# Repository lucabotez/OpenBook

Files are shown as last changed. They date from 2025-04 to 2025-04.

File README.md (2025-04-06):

Botez Luca, 334CA

# OpenBook

## About
This project is a minimalist eBook Reader called OpenBook, built on the ESP32-C6 platform and equipped with a 7.5-inch e-paper display, a Li-Po battery, USB-C charging, and physical control buttons.

The device is designed to be energy-efficient and easy to use, featuring a simple interface controlled via GPIOs, with text display functions aimed at providing an optimal e-reading experience.

## Block Diagram

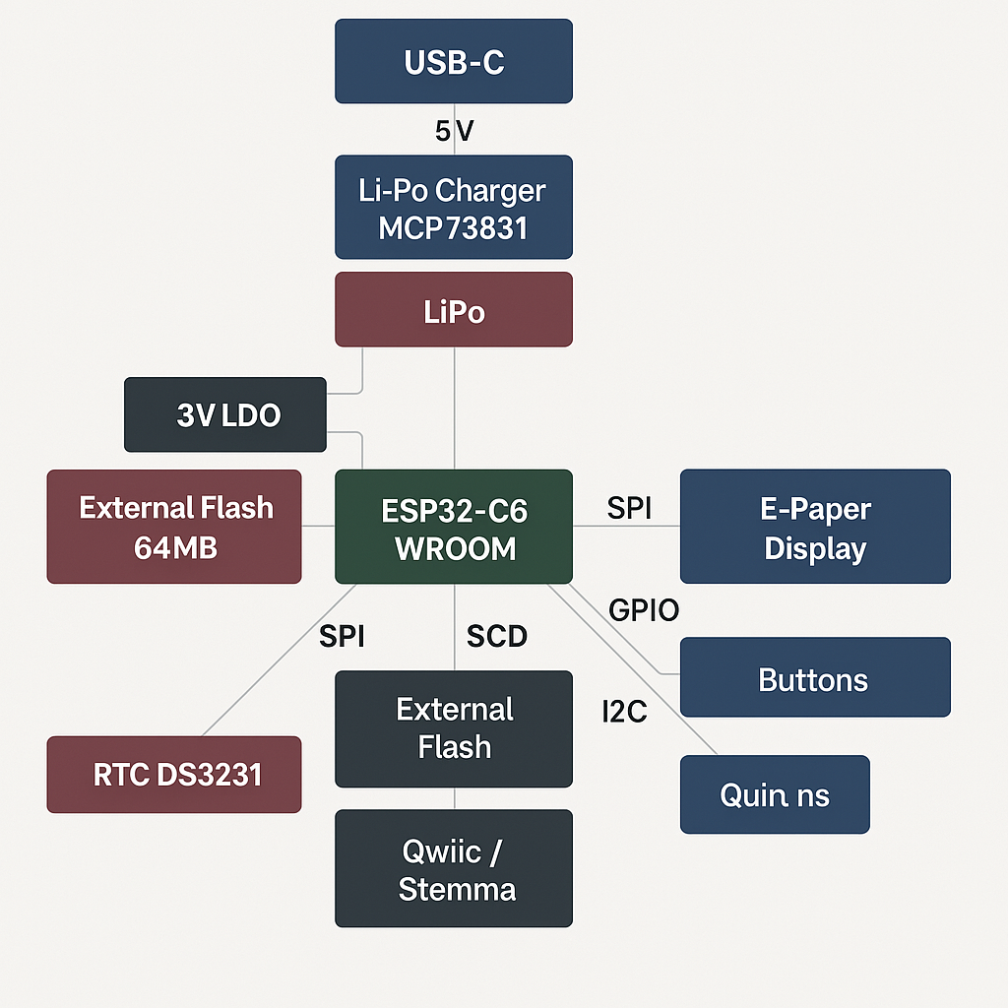
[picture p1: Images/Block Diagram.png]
Block Diagram


## BOM (Bill of Materials)

| Component | Purchase Link | Datasheet |
|---|---|---|
| BOOT_BUTTON | [https://ro.mouser.com/ProductDetail/Panasonic/EVQ-P7L01P](https://ro.mouser.com/ProductDetail/Panasonic/EVQ-P7L01P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) | https://componentsearchengine.com/Datasheets/2/EVQP7L01P.pdf |
| C1 | [https://ro.mouser.com/ProductDetail/YAGEO/CC0402MRX5R5BB106](https://ro.mouser.com/ProductDetail/YAGEO/CC0402MRX5R5BB106?qs=zEY9bCHj09eCmUJdZuS5Lg%3D%3D) | https://componentsearchengine.com/Datasheets/2/CC0402MRX5R5BB106.pdf |
| C1_BAT | [https://ro.mouser.com/ProductDetail/YAGEO/CC0402MRX5R5BB106](https://ro.mouser.com/ProductDetail/YAGEO/CC0402MRX5R5BB106?qs=zEY9bCHj09eCmUJdZuS5Lg%3D%3D) | https://componentsearchengine.com/Datasheets/2/CC0402MRX5R5BB106.pdf |
| C1_BAT2 | [https://ro.mouser.com/ProductDetail/YAGEO/CC0402MRX5R5BB106](https://ro.mouser.com/ProductDetail/YAGEO/CC0402MRX5R5BB106?qs=zEY9bCHj09eCmUJdZuS5Lg%3D%3D) | https://componentsearchengine.com/Datasheets/2/CC0402MRX5R5BB106.pdf |
| C2 | [https://ro.mouser.com/ProductDetail/YAGEO/CC0402MRX5R5BB106](https://ro.mouser.com/ProductDetail/YAGEO/CC0402MRX5R5BB106?qs=zEY9bCHj09eCmUJdZuS5Lg%3D%3D) | https://componentsearchengine.com/Datasheets/2/CC0402MRX5R5BB106.pdf |
| C2_BAT | [https://ro.mouser.com/ProductDetail/YAGEO/CC0402MRX5R5BB106](https://ro.mouser.com/ProductDetail/YAGEO/CC0402MRX5R5BB106?qs=zEY9bCHj09eCmUJdZuS5Lg%3D%3D) | https://componentsearchengine.com/Datasheets/2/CC0402MRX5R5BB106.pdf |
| C3 | [https://ro.mouser.com/ProductDetail/YAGEO/CC0402MRX5R5BB106](https://ro.mouser.com/ProductDetail/YAGEO/CC0402MRX5R5BB106?qs=zEY9bCHj09eCmUJdZuS5Lg%3D%3D) | https://componentsearchengine.com/Datasheets/2/CC0402MRX5R5BB106.pdf |
| C4 | [https://ro.mouser.com/ProductDetail/YAGEO/CC0402MRX5R5BB106](https://ro.mouser.com/ProductDetail/YAGEO/CC0402MRX5R5BB106?qs=zEY9bCHj09eCmUJdZuS5Lg%3D%3D) | https://componentsearchengine.com/Datasheets/2/CC0402MRX5R5BB106.pdf |
| C4_USB | [https://ro.mouser.com/ProductDetail/YAGEO/CC0402MRX5R5BB106](https://ro.mouser.com/ProductDetail/YAGEO/CC0402MRX5R5BB106?qs=zEY9bCHj09eCmUJdZuS5Lg%3D%3D) | https://componentsearchengine.com/Datasheets/2/CC0402MRX5R5BB106.pdf |
| C5 | [https://ro.mouser.com/ProductDetail/YAGEO/CC0402MRX5R5BB106](https://ro.mouser.com/ProductDetail/YAGEO/CC0402MRX5R5BB106?qs=zEY9bCHj09eCmUJdZuS5Lg%3D%3D) | https://componentsearchengine.com/Datasheets/2/CC0402MRX5R5BB106.pdf |
| C5_USB | [https://ro.mouser.com/ProductDetail/YAGEO/CC0402MRX5R5BB106](https://ro.mouser.com/ProductDetail/YAGEO/CC0402MRX5R5BB106?qs=zEY9bCHj09eCmUJdZuS5Lg%3D%3D) | https://componentsearchengine.com/Datasheets/2/CC0402MRX5R5BB106.pdf |
| C6 | [https://ro.mouser.com/ProductDetail/YAGEO/CC0402MRX5R5BB106](https://ro.mouser.com/ProductDetail/YAGEO/CC0402MRX5R5BB106?qs=zEY9bCHj09eCmUJdZuS5Lg%3D%3D) | https://componentsearchengine.com/Datasheets/2/CC0402MRX5R5BB106.pdf |
| C7 | [https://ro.mouser.com/ProductDetail/YAGEO/CC0402MRX5R5BB106](https://ro.mouser.com/ProductDetail/YAGEO/CC0402MRX5R5BB106?qs=zEY9bCHj09eCmUJdZuS5Lg%3D%3D) | https://componentsearchengine.com/Datasheets/2/CC0402MRX5R5BB106.pdf |
| C8 | [https://ro.mouser.com/ProductDetail/YAGEO/CC0402MRX5R5BB106](https://ro.mouser.com/ProductDetail/YAGEO/CC0402MRX5R5BB106?qs=zEY9bCHj09eCmUJdZuS5Lg%3D%3D) | https://componentsearchengine.com/Datasheets/2/CC0402MRX5R5BB106.pdf |
| C9 | [https://ro.mouser.com/ProductDetail/YAGEO/CC0402MRX5R5BB106](https://ro.mouser.com/ProductDetail/YAGEO/CC0402MRX5R5BB106?qs=zEY9bCHj09eCmUJdZuS5Lg%3D%3D) | https://componentsearchengine.com/Datasheets/2/CC0402MRX5R5BB106.pdf |
| C10 | [https://ro.mouser.com/ProductDetail/YAGEO/CC0402MRX5R5BB106](https://ro.mouser.com/ProductDetail/YAGEO/CC0402MRX5R5BB106?qs=zEY9bCHj09eCmUJdZuS5Lg%3D%3D) | https://componentsearchengine.com/Datasheets/2/CC0402MRX5R5BB106.pdf |
| C10_SUPERCAP | [https://ro.mouser.com/ProductDetail/Seiko-Semiconductors/CPH3225A](https://ro.mouser.com/ProductDetail/Seiko-Semiconductors/CPH3225A?qs=3etwrb1wR%252BhUOph6lAO7eg%3D%3D) | https://ro.mouser.com/datasheet/2/360/Seiko_Instruments_MicroBattery_E_20230330_2024Jan_-3561061.pdf |
| CHANGE_BUTTON | [https://ro.mouser.com/ProductDetail/Panasonic/EVQ-P7L01P](https://ro.mouser.com/ProductDetail/Panasonic/EVQ-P7L01P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) | https://componentsearchengine.com/Datasheets/2/EVQP7L01P.pdf |
| C_DELAY | [https://ro.mouser.com/ProductDetail/YAGEO/CC0402MRX5R5BB106](https://ro.mouser.com/ProductDetail/YAGEO/CC0402MRX5R5BB106?qs=zEY9bCHj09eCmUJdZuS5Lg%3D%3D) | https://componentsearchengine.com/Datasheets/2/CC0402MRX5R5BB106.pdf |
| D1 | [https://ro.mouser.com/ProductDetail/STMicroelectronics/USBLC6-2SC6Y](https://ro.mouser.com/ProductDetail/STMicroelectronics/USBLC6-2SC6Y?qs=gNDSiZmRJS%2FOgDexvXkdow%3D%3D) | https://ro.mouser.com/datasheet/2/389/usblc6_2sc6y-1852505.pdf |
| D2 | [https://ro.mouser.com/ProductDetail/KYOCERA-AVX/SD0805S020S1R0](https://ro.mouser.com/ProductDetail/KYOCERA-AVX/SD0805S020S1R0?qs=jCA%252BPfw4LHbpkAoSnwrdjw%3D%3D) | https://ro.mouser.com/datasheet/2/40/schottky-3165252.pdf |
| D3 | [https://ro.mouser.com/ProductDetail/Vishay-Semiconductors/MBR0530](https://ro.mouser.com/ProductDetail/Vishay-Semiconductors/MBR0530?qs=HoksaeI1MJOP4GvpzMgEDg%3D%3D) | https://www.onsemi.com/pdf/datasheet/mbr0530-d.pdf |
| D4 | [https://ro.mouser.com/ProductDetail/Vishay-Semiconductors/MBR0530](https://ro.mouser.com/ProductDetail/Vishay-Semiconductors/MBR0530?qs=HoksaeI1MJOP4GvpzMgEDg%3D%3D) | https://www.onsemi.com/pdf/datasheet/mbr0530-d.pdf |
| D5 | [https://ro.mouser.com/ProductDetail/Vishay-Semiconductors/MBR0530](https://ro.mouser.com/ProductDetail/Vishay-Semiconductors/MBR0530?qs=HoksaeI1MJOP4GvpzMgEDg%3D%3D) | https://www.onsemi.com/pdf/datasheet/mbr0530-d.pdf |
| D6 | [https://ro.mouser.com/ProductDetail/Littelfuse/PGB1010603MR](https://ro.mouser.com/ProductDetail/Littelfuse/PGB1010603MR?qs=gu7KAQ731URLg4GSnNNN7Q%3D%3D) | https://www.littelfuse.com/assetdocs/pulseguard-esd-suppressors-pgb1-datasheet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 |
| D7 | [https://ro.mouser.com/ProductDetail/KYOCERA-AVX/SD0805S020S1R0](https://ro.mouser.com/ProductDetail/KYOCERA-AVX/SD0805S020S1R0?qs=jCA%252BPfw4LHbpkAoSnwrdjw%3D%3D) | https://ro.mouser.com/datasheet/2/40/schottky-3165252.pdf |
| D8 | [https://ro.mouser.com/ProductDetail/Littelfuse/PGB1010603MR](https://ro.mouser.com/ProductDetail/Littelfuse/PGB1010603MR?qs=gu7KAQ731URLg4GSnNNN7Q%3D%3D) | https://www.littelfuse.com/assetdocs/pulseguard-esd-suppressors-pgb1-datasheet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 |
| D9 | [https://ro.mouser.com/ProductDetail/Littelfuse/PGB1010603MR](https://ro.mouser.com/ProductDetail/Littelfuse/PGB1010603MR?qs=gu7KAQ731URLg4GSnNNN7Q%3D%3D) | https://www.littelfuse.com/assetdocs/pulseguard-esd-suppressors-pgb1-datasheet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 |
| D10 | [https://ro.mouser.com/ProductDetail/Littelfuse/PGB1010603MR](https://ro.mouser.com/ProductDetail/Littelfuse/PGB1010603MR?qs=gu7KAQ731URLg4GSnNNN7Q%3D%3D) | https://www.littelfuse.com/assetdocs/pulseguard-esd-suppressors-pgb1-datasheet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 |
| D11 | [https://ro.mouser.com/ProductDetail/Littelfuse/PGB1010603MR](https://ro.mouser.com/ProductDetail/Littelfuse/PGB1010603MR?qs=gu7KAQ731URLg4GSnNNN7Q%3D%3D) | https://www.littelfuse.com/assetdocs/pulseguard-esd-suppressors-pgb1-datasheet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 |
| D12 | [https://ro.mouser.com/ProductDetail/Littelfuse/PGB1010603MR](https://ro.mouser.com/ProductDetail/Littelfuse/PGB1010603MR?qs=gu7KAQ731URLg4GSnNNN7Q%3D%3D) | https://www.littelfuse.com/assetdocs/pulseguard-esd-suppressors-pgb1-datasheet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 |
| EPD_C1 | [https://ro.mouser.com/ProductDetail/YAGEO/CC0402MRX5R5BB106](https://ro.mouser.com/ProductDetail/YAGEO/CC0402MRX5R5BB106?qs=zEY9bCHj09eCmUJdZuS5Lg%3D%3D) | https://componentsearchengine.com/Datasheets/2/CC0402MRX5R5BB106.pdf |
| EPD_C2 | [https://ro.mouser.com/ProductDetail/YAGEO/CC0402MRX5R5BB106](https://ro.mouser.com/ProductDetail/YAGEO/CC0402MRX5R5BB106?qs=zEY9bCHj09eCmUJdZuS5Lg%3D%3D) | https://componentsearchengine.com/Datasheets/2/CC0402MRX5R5BB106.pdf |
| EPD_C3 | [https://ro.mouser.com/ProductDetail/YAGEO/CC0402MRX5R5BB106](https://ro.mouser.com/ProductDetail/YAGEO/CC0402MRX5R5BB106?qs=zEY9bCHj09eCmUJdZuS5Lg%3D%3D) | https://componentsearchengine.com/Datasheets/2/CC0402MRX5R5BB106.pdf |
| EPD_C4 | [https://ro.mouser.com/ProductDetail/YAGEO/CC0402MRX5R5BB106](https://ro.mouser.com/ProductDetail/YAGEO/CC0402MRX5R5BB106?qs=zEY9bCHj09eCmUJdZuS5Lg%3D%3D) | https://componentsearchengine.com/Datasheets/2/CC0402MRX5R5BB106.pdf |
| EPD_C5 | [https://ro.mouser.com/ProductDetail/YAGEO/CC0402MRX5R5BB106](https://ro.mouser.com/ProductDetail/YAGEO/CC0402MRX5R5BB106?qs=zEY9bCHj09eCmUJdZuS5Lg%3D%3D) | https://componentsearchengine.com/Datasheets/2/CC0402MRX5R5BB106.pdf |
| EPD_C6 | [https://ro.mouser.com/ProductDetail/YAGEO/CC0402MRX5R5BB106](https://ro.mouser.com/ProductDetail/YAGEO/CC0402MRX5R5BB106?qs=zEY9bCHj09eCmUJdZuS5Lg%3D%3D) | https://componentsearchengine.com/Datasheets/2/CC0402MRX5R5BB106.pdf |
| EPD_C7 | [https://ro.mouser.com/ProductDetail/YAGEO/CC0402MRX5R5BB106](https://ro.mouser.com/ProductDetail/YAGEO/CC0402MRX5R5BB106?qs=zEY9bCHj09eCmUJdZuS5Lg%3D%3D) | https://componentsearchengine.com/Datasheets/2/CC0402MRX5R5BB106.pdf |
| EPD_C8 | [https://ro.mouser.com/ProductDetail/YAGEO/CC0402MRX5R5BB106](https://ro.mouser.com/ProductDetail/YAGEO/CC0402MRX5R5BB106?qs=zEY9bCHj09eCmUJdZuS5Lg%3D%3D) | https://componentsearchengine.com/Datasheets/2/CC0402MRX5R5BB106.pdf |
| EPD_C9 | [https://ro.mouser.com/ProductDetail/YAGEO/CC0402MRX5R5BB106](https://ro.mouser.com/ProductDetail/YAGEO/CC0402MRX5R5BB106?qs=zEY9bCHj09eCmUJdZuS5Lg%3D%3D) | https://componentsearchengine.com/Datasheets/2/CC0402MRX5R5BB106.pdf |
| EPD_C10 | [https://ro.mouser.com/ProductDetail/YAGEO/CC0402MRX5R5BB106](https://ro.mouser.com/ProductDetail/YAGEO/CC0402MRX5R5BB106?qs=zEY9bCHj09eCmUJdZuS5Lg%3D%3D) | https://componentsearchengine.com/Datasheets/2/CC0402MRX5R5BB106.pdf |
| EPD_C11 | [https://ro.mouser.com/ProductDetail/YAGEO/CC0402MRX5R5BB106](https://ro.mouser.com/ProductDetail/YAGEO/CC0402MRX5R5BB106?qs=zEY9bCHj09eCmUJdZuS5Lg%3D%3D) | https://componentsearchengine.com/Datasheets/2/CC0402MRX5R5BB106.pdf |
| EPD_C12 | [https://ro.mouser.com/ProductDetail/YAGEO/CC0402MRX5R5BB106](https://ro.mouser.com/ProductDetail/YAGEO/CC0402MRX5R5BB106?qs=zEY9bCHj09eCmUJdZuS5Lg%3D%3D) | https://componentsearchengine.com/Datasheets/2/CC0402MRX5R5BB106.pdf |
| IC1 | [https://ro.mouser.com/ProductDetail/ROHM-Semiconductor/BD5229G-TR](https://ro.mouser.com/ProductDetail/ROHM-Semiconductor/BD5229G-TR?qs=4kLU8WoGk0vvnhrrYwdszw%3D%3D) | https://fscdn.rohm.com/en/products/databook/datasheet/ic/power/voltage_detector/bd52xxg-e.pdf |
| IC4 | [https://ro.mouser.com/ProductDetail/Torex-Semiconductor/XC6220A331MR-G](https://ro.mouser.com/ProductDetail/Torex-Semiconductor/XC6220A331MR-G?qs=AsjdqWjXhJ8ZSWznL1J0gg%3D%3D) | https://ro.mouser.com/datasheet/2/760/xc6220-3371556.pdf |
| J1 | [https://ro.mouser.com/ProductDetail/Hirose-Connector/FH34SRJ-24S-0.5SH99](https://ro.mouser.com/ProductDetail/Hirose-Connector/FH34SRJ-24S-0.5SH99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) | https://ro.mouser.com/datasheet/2/185/FH34SRJ_24S_0_5SH_99__CL0580_1255_6_99_2DDrawing_0-1615044.pdf |
| J2 | [https://ro.mouser.com/ProductDetail/GCT/USB4110-GF-A](https://ro.mouser.com/ProductDetail/GCT/USB4110-GF-A?qs=KUoIvG%2F9IlYiZvIXQjyJeA%3D%3D) | https://ro.mouser.com/datasheet/2/837/GCT_USB4110_Product_Drawing___20k_cycles-3455479.pdf |
| J3 | [https://ro.mouser.com/ProductDetail/SparkFun/PRT-14417](https://ro.mouser.com/ProductDetail/SparkFun/PRT-14417?qs=wd5RIQLrsJhgdz%2FpmZ%2F3GQ%3D%3D) | https://ro.mouser.com/datasheet/2/813/Qwiic_Connector_Datasheet-1223982.pdf |
| J4 | https://store.comet.srl.ro/Catalogue/Product/43497/ | https://store.comet.bg/download-file.php?id=8824 |
| L1 | [https://ro.mouser.com/ProductDetail/Wurth-Elektronik/744043680](https://ro.mouser.com/ProductDetail/Wurth-Elektronik/744043680?qs=PGXP4M47uW6VkZq%252BkzjrHA%3D%3D) | https://www.we-online.com/components/products/datasheet/744043680.pdf |
| PFMF.050.1 | [https://ro.mouser.com/ProductDetail/KEMET/VE1812K401R050](https://ro.mouser.com/ProductDetail/KEMET/VE1812K401R050?qs=OycAS1CGnlizCtaoDVbQTA%3D%3D) | https://ro.mouser.com/datasheet/2/447/KEM_V0003_VE-3316901.pdf |
| Q1 | [https://ro.mouser.com/ProductDetail/Diodes-Incorporated/DMG2305UX-7](https://ro.mouser.com/ProductDetail/Diodes-Incorporated/DMG2305UX-7?qs=L1DZKBg7t5F%2FNBHrjfxC%252Bg%3D%3D) | https://www.diodes.com/assets/Datasheets/DMG2305UX.pdf |
| Q2 | [https://ro.mouser.com/ProductDetail/Diodes-Incorporated/DMG2305UX-7](https://ro.mouser.com/ProductDetail/Diodes-Incorporated/DMG2305UX-7?qs=L1DZKBg7t5F%2FNBHrjfxC%252Bg%3D%3D) | https://www.diodes.com/assets/Datasheets/DMG2305UX.pdf |
| Q3 | [https://ro.mouser.com/ProductDetail/Vishay-Semiconductors/SI1308EDL-T1-GE3](https://ro.mouser.com/ProductDetail/Vishay-Semiconductors/SI1308EDL-T1-GE3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) | https://www.vishay.com/docs/63399/si1308edl.pdf |
| R1 | [https://ro.mouser.com/ProductDetail/YAGEO/RC0402FR-07100KL](https://ro.mouser.com/ProductDetail/YAGEO/RC0402FR-07100KL?qs=mnq%2FyloZIXzTlUn7JAHSWg%3D%3D) | https://ro.mouser.com/datasheet/2/447/YAGEO_PYu_RC_Group_51_RoHS_L_12-3313492.pdf |
| R1_PINH | [https://ro.mouser.com/ProductDetail/YAGEO/RC0402FR-07100KL](https://ro.mouser.com/ProductDetail/YAGEO/RC0402FR-07100KL?qs=mnq%2FyloZIXzTlUn7JAHSWg%3D%3D) | https://ro.mouser.com/datasheet/2/447/YAGEO_PYu_RC_Group_51_RoHS_L_12-3313492.pdf |
| R1_PINH1 | [https://ro.mouser.com/ProductDetail/YAGEO/RC0402FR-07100KL](https://ro.mouser.com/ProductDetail/YAGEO/RC0402FR-07100KL?qs=mnq%2FyloZIXzTlUn7JAHSWg%3D%3D) | https://ro.mouser.com/datasheet/2/447/YAGEO_PYu_RC_Group_51_RoHS_L_12-3313492.pdf |
| R1_BAT | [https://ro.mouser.com/ProductDetail/YAGEO/RC0402FR-07100KL](https://ro.mouser.com/ProductDetail/YAGEO/RC0402FR-07100KL?qs=mnq%2FyloZIXzTlUn7JAHSWg%3D%3D) | https://ro.mouser.com/datasheet/2/447/YAGEO_PYu_RC_Group_51_RoHS_L_12-3313492.pdf |
| R1_PWRUSB | [https://ro.mouser.com/ProductDetail/YAGEO/RC0402FR-07100KL](https://ro.mouser.com/ProductDetail/YAGEO/RC0402FR-07100KL?qs=mnq%2FyloZIXzTlUn7JAHSWg%3D%3D) | https://ro.mouser.com/datasheet/2/447/YAGEO_PYu_RC_Group_51_RoHS_L_12-3313492.pdf |
| R2 | [https://ro.mouser.com/ProductDetail/YAGEO/RC0402FR-07100KL](https://ro.mouser.com/ProductDetail/YAGEO/RC0402FR-07100KL?qs=mnq%2FyloZIXzTlUn7JAHSWg%3D%3D) | https://ro.mouser.com/datasheet/2/447/YAGEO_PYu_RC_Group_51_RoHS_L_12-3313492.pdf |
| R2_PINH | [https://ro.mouser.com/ProductDetail/YAGEO/RC0402FR-07100KL](https://ro.mouser.com/ProductDetail/YAGEO/RC0402FR-07100KL?qs=mnq%2FyloZIXzTlUn7JAHSWg%3D%3D) | https://ro.mouser.com/datasheet/2/447/YAGEO_PYu_RC_Group_51_RoHS_L_12-3313492.pdf |
| R2_PINH1 | [https://ro.mouser.com/ProductDetail/YAGEO/RC0402FR-07100KL](https://ro.mouser.com/ProductDetail/YAGEO/RC0402FR-07100KL?qs=mnq%2FyloZIXzTlUn7JAHSWg%3D%3D) | https://ro.mouser.com/datasheet/2/447/YAGEO_PYu_RC_Group_51_RoHS_L_12-3313492.pdf |
| R2_USB | [https://ro.mouser.com/ProductDetail/YAGEO/RC0402FR-07100KL](https://ro.mouser.com/ProductDetail/YAGEO/RC0402FR-07100KL?qs=mnq%2FyloZIXzTlUn7JAHSWg%3D%3D) | https://ro.mouser.com/datasheet/2/447/YAGEO_PYu_RC_Group_51_RoHS_L_12-3313492.pdf |
| R2_USB1 | [https://ro.mouser.com/ProductDetail/YAGEO/RC0402FR-07100KL](https://ro.mouser.com/ProductDetail/YAGEO/RC0402FR-07100KL?qs=mnq%2FyloZIXzTlUn7JAHSWg%3D%3D) | https://ro.mouser.com/datasheet/2/447/YAGEO_PYu_RC_Group_51_RoHS_L_12-3313492.pdf |
| R2_BAT | [https://ro.mouser.com/ProductDetail/YAGEO/RC0402FR-07100KL](https://ro.mouser.com/ProductDetail/YAGEO/RC0402FR-07100KL?qs=mnq%2FyloZIXzTlUn7JAHSWg%3D%3D) | https://ro.mouser.com/datasheet/2/447/YAGEO_PYu_RC_Group_51_RoHS_L_12-3313492.pdf |
| R3 | [https://ro.mouser.com/ProductDetail/YAGEO/RC0402FR-07100KL](https://ro.mouser.com/ProductDetail/YAGEO/RC0402FR-07100KL?qs=mnq%2FyloZIXzTlUn7JAHSWg%3D%3D) | https://ro.mouser.com/datasheet/2/447/YAGEO_PYu_RC_Group_51_RoHS_L_12-3313492.pdf |
| R4 | [https://ro.mouser.com/ProductDetail/YAGEO/RC0402FR-07100KL](https://ro.mouser.com/ProductDetail/YAGEO/RC0402FR-07100KL?qs=mnq%2FyloZIXzTlUn7JAHSWg%3D%3D) | https://ro.mouser.com/datasheet/2/447/YAGEO_PYu_RC_Group_51_RoHS_L_12-3313492.pdf |
| R5 | [https://ro.mouser.com/ProductDetail/YAGEO/RC0402FR-07100KL](https://ro.mouser.com/ProductDetail/YAGEO/RC0402FR-07100KL?qs=mnq%2FyloZIXzTlUn7JAHSWg%3D%3D) | https://ro.mouser.com/datasheet/2/447/YAGEO_PYu_RC_Group_51_RoHS_L_12-3313492.pdf |
| R6 | [https://ro.mouser.com/ProductDetail/YAGEO/RC0402FR-07100KL](https://ro.mouser.com/ProductDetail/YAGEO/RC0402FR-07100KL?qs=mnq%2FyloZIXzTlUn7JAHSWg%3D%3D) | https://ro.mouser.com/datasheet/2/447/YAGEO_PYu_RC_Group_51_RoHS_L_12-3313492.pdf |
| R7 | [https://ro.mouser.com/ProductDetail/YAGEO/RC0402FR-07100KL](https://ro.mouser.com/ProductDetail/YAGEO/RC0402FR-07100KL?qs=mnq%2FyloZIXzTlUn7JAHSWg%3D%3D) | https://ro.mouser.com/datasheet/2/447/YAGEO_PYu_RC_Group_51_RoHS_L_12-3313492.pdf |
| R8 | [https://ro.mouser.com/ProductDetail/YAGEO/RC0402FR-07100KL](https://ro.mouser.com/ProductDetail/YAGEO/RC0402FR-07100KL?qs=mnq%2FyloZIXzTlUn7JAHSWg%3D%3D) | https://ro.mouser.com/datasheet/2/447/YAGEO_PYu_RC_Group_51_RoHS_L_12-3313492.pdf |
| R9 | [https://ro.mouser.com/ProductDetail/YAGEO/RC0402FR-07100KL](https://ro.mouser.com/ProductDetail/YAGEO/RC0402FR-07100KL?qs=mnq%2FyloZIXzTlUn7JAHSWg%3D%3D) | https://ro.mouser.com/datasheet/2/447/YAGEO_PYu_RC_Group_51_RoHS_L_12-3313492.pdf |
| R10 | [https://ro.mouser.com/ProductDetail/YAGEO/RC0402FR-07100KL](https://ro.mouser.com/ProductDetail/YAGEO/RC0402FR-07100KL?qs=mnq%2FyloZIXzTlUn7JAHSWg%3D%3D) | https://ro.mouser.com/datasheet/2/447/YAGEO_PYu_RC_Group_51_RoHS_L_12-3313492.pdf |
| RESET_BUTTON | [https://ro.mouser.com/ProductDetail/Panasonic/EVQ-P7L01P](https://ro.mouser.com/ProductDetail/Panasonic/EVQ-P7L01P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) | https://componentsearchengine.com/Datasheets/2/EVQP7L01P.pdf |
| R_BOOT | [https://ro.mouser.com/ProductDetail/YAGEO/RC0402FR-07100KL](https://ro.mouser.com/ProductDetail/YAGEO/RC0402FR-07100KL?qs=mnq%2FyloZIXzTlUn7JAHSWg%3D%3D) | https://ro.mouser.com/datasheet/2/447/YAGEO_PYu_RC_Group_51_RoHS_L_12-3313492.pdf |
| R_CAPACITOR | [https://ro.mouser.com/ProductDetail/YAGEO/RC0402FR-07100KL](https://ro.mouser.com/ProductDetail/YAGEO/RC0402FR-07100KL?qs=mnq%2FyloZIXzTlUn7JAHSWg%3D%3D) | https://ro.mouser.com/datasheet/2/447/YAGEO_PYu_RC_Group_51_RoHS_L_12-3313492.pdf |
| R_CHANGE | [https://ro.mouser.com/ProductDetail/YAGEO/RC0402FR-07100KL](https://ro.mouser.com/ProductDetail/YAGEO/RC0402FR-07100KL?qs=mnq%2FyloZIXzTlUn7JAHSWg%3D%3D) | https://ro.mouser.com/datasheet/2/447/YAGEO_PYu_RC_Group_51_RoHS_L_12-3313492.pdf |
| R_CL1 | [https://ro.mouser.com/ProductDetail/YAGEO/RC0402FR-07100KL](https://ro.mouser.com/ProductDetail/YAGEO/RC0402FR-07100KL?qs=mnq%2FyloZIXzTlUn7JAHSWg%3D%3D) | https://ro.mouser.com/datasheet/2/447/YAGEO_PYu_RC_Group_51_RoHS_L_12-3313492.pdf |
| R_RESET | [https://ro.mouser.com/ProductDetail/YAGEO/RC0402FR-07100KL](https://ro.mouser.com/ProductDetail/YAGEO/RC0402FR-07100KL?qs=mnq%2FyloZIXzTlUn7JAHSWg%3D%3D) | https://ro.mouser.com/datasheet/2/447/YAGEO_PYu_RC_Group_51_RoHS_L_12-3313492.pdf |
| SENSOR2 | [https://ro.mouser.com/ProductDetail/Bosch-Sensortec/BME680](https://ro.mouser.com/ProductDetail/Bosch-Sensortec/BME680?qs=v271MhAjFHjo0yA%2FC4OnDQ%3D%3D) | https://ro.mouser.com/datasheet/2/783/BST_BME680_DS001-1509608.pdf |
| SJ1 | https://grabcad.com/library/solder-jumpers-1 | https://grabcad.com/library/solder-jumpers-1 |
| TP1 | CUSTOM | CUSTOM |
| TP2 | CUSTOM | CUSTOM |
| TP3 | CUSTOM | CUSTOM |
| TP4 | CUSTOM | CUSTOM |
| TP5 | CUSTOM | CUSTOM |
| TP6 | CUSTOM | CUSTOM |
| TP7 | CUSTOM | CUSTOM |
| TP8 | CUSTOM | CUSTOM |
| TP9 | CUSTOM | CUSTOM |
| TP10 | CUSTOM | CUSTOM |
| TP11 | CUSTOM | CUSTOM |
| TP12 | CUSTOM | CUSTOM |
| TP13 | CUSTOM | CUSTOM |
| TP14 | CUSTOM | CUSTOM |
| TP15 | CUSTOM | CUSTOM |
| TP16 | CUSTOM | CUSTOM |
| TP17 | CUSTOM | CUSTOM |
| U1 | [https://ro.mouser.com/ProductDetail/Winbond/W25Q512JVEIQ](https://ro.mouser.com/ProductDetail/Winbond/W25Q512JVEIQ?qs=l7cgNqFNU1jw6svr3at6tA%3D%3D) | https://ro.mouser.com/datasheet/2/949/Winbond_W25Q512JV_Datasheet-3240039.pdf |
| U2 | [https://ro.mouser.com/ProductDetail/Espressif-Systems/ESP32-C6-WROOM-1-N8](https://ro.mouser.com/ProductDetail/Espressif-Systems/ESP32-C6-WROOM-1-N8?qs=8Wlm6%252BaMh8ST02Gmwp74cw%3D%3D) | https://ro.mouser.com/datasheet/2/891/Espressif_ESP32_C6_WROOM_1__Datasheet_V0_1_PRELIMI-3239987.pdf |
| U3 | [https://ro.mouser.com/ProductDetail/Analog-Devices-Maxim-Integrated/DS3231SN](https://ro.mouser.com/ProductDetail/Analog-Devices-Maxim-Integrated/DS3231SN?qs=1eQvB6Dk1vhUlr8%2FOrV0Fw%3D%3D) | https://ro.mouser.com/datasheet/2/609/DS3231-3421123.pdf |
| U4 | [https://ro.mouser.com/ProductDetail/Analog-Devices-Maxim-Integrated/MAX17048G+T10](https://ro.mouser.com/ProductDetail/Analog-Devices-Maxim-Integrated/MAX17048G%2bT10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) | https://ro.mouser.com/datasheet/2/609/MAX17048_MAX17049-3469099.pdf |
| U5 | [https://ro.mouser.com/ProductDetail/Microchip-Technology/MCP73831T-2ACI-OT](https://ro.mouser.com/ProductDetail/Microchip-Technology/MCP73831T-2ACI-OT?qs=yUQqVecv4qvbBQBGbHx0Mw%3D%3D) | https://ro.mouser.com/datasheet/2/268/MCP73831_Family_Data_Sheet_DS20001984H-3441711.pdf |

## Hardware Description

- **ESP32-C6-WROOM-1-N8** – Main microcontroller with integrated **Wi-Fi** and **BLE**; manages communication, sensors, and display.
- **BME688** – Environmental and air quality sensor (**temperature**, **humidity**, **pressure**, **gas**); connected via **I²C**.
- **DS3231SN** – High-precision **RTC (Real-Time Clock)** module for maintaining accurate time; connected via **I²C**.
- **MAX17048** – Battery level monitor with **I²C** interface, provides **State of Charge (SOC)** estimation.
- **SD Card Module** – Used for local data storage; communicates with the ESP32 via **SPI**.
- **E-Ink Display** – Low-power **e-paper display** with **SPI** interface; includes signals like `EPD_CS`, `EPD_DC`, `EPD_RST`, `EPD_BUSY`.
- **W25Q512JVEIQ (64MB NOR Flash)** – External **SPI** flash memory for storing firmware or large datasets.
- **BOOT and RESET Buttons** – Connected to **GPIO** for bootloader activation and system reset control.
- **MCP73831** – **Li-Po battery charging controller**, directly manages the charging process.
- **XC6220A331MR-G (LDO Regulator)** – **3.3V voltage regulator** that powers logic circuits from battery or USB input.
- **USB-C Port (USB4110-GF-A)** – Provides **power input** and **serial interface** for code upload and debugging.

## Detailed ESP32-C6 View

**IO0 - INT_RTC**
- Interrupt signal that can wake up the ESP32 from deep sleep.
- Used by RTC.

**IO1 – 32KHZ**
- The DS3231’s 32.768 kHz clock output, routed to the ESP32‐C6.
- Used by ESP32‐C6.

**IO2 – MISO**
- Hardware-dedicated SPI pin, offering high speed and native compatibility.
- Used by NOR Flash, E-Paper, microSD.

**IO3 - EPD_BUSY**
- GPIO status signal sent by the EPD driver, ESP32 reads it to check if the screen is busy.
- Used by E-Paper Display.

**IO4 – SS_SD**
- Selects the SD card during reading; chosen to avoid conflicts with other CS lines already in use.
- Used by microSD Card.

**IO5 – EPD_DC**
- Control signal specific to EPD to differentiate between commands and data.
- Used by E-Paper Display.

**IO6 – SCK**
- Recommended pin for SPI clock in multi-device implementations; allows SPI bus sharing.
- Used by NOR Flash, E-Paper, microSD.

**IO7 – MOSI**
- Utilized for SPI data transmission, compatible with all connected SPI peripherals.
- Used by NOR Flash, E-Paper, microSD.

**IO9 – IO/BOOT**
- Standard pin for entering programming mode on the ESP32-C6.
- Used by BOOT Button.

**IO10 - EPD_CS**
- Selects the display during SPI transfers; doesn’t interfere with the rest of the SPI devices.
- Used by E-Paper Display.

**IO11 – FLASH_CS**
- Dedicated pin to activate the external Flash memory without interfering with other SPI peripherals.
- Used by External NOR Flash Memory.

**IO12 – USB_D-**
- Direct USB data lines for the built‐in USB peripheral, going to the USB connector.
- Used by USB-C connector.

**IO13 – USB_D+**
- Direct USB data lines for the built‐in USB peripheral, going to the USB connector.
- Used by USB-C connector.

**IO15 – IO/CHANGE**
- General-purpose GPIO chosen for user-defined actions (e.g. Next Page).
- Used by CHANGE Button.

**IO16 – TX**
- Traditional serial line used for flashing the older ESP chips and debug logs.
- Used by Serial Debug.

**IO17 – RX**
- Traditional serial line used for flashing the older ESP chips and debug logs.
- Used by Serial Debug.

**IO18 – RTC_RST**
- External manual reset for the RTC, useful for initial synchronization or watchdog purposes.
- Used by RTC.

**IO19 – I2C_PW**
- 3.3V rail dedicated to powering I2C peripherals (sensors, RTC, battery gauge).
- Used by RTC, BME680, Qwiic.

**IO20 – EPD_3V3_C**
- 3.3V supply line that powers the E‐paper Display module.
- Used by E-Paper Display.

**IO21 – SDA**
- Data line for I2C communication; can be shared between multiple sensors.
- Used by RTC, BME680, Qwiic.

**IO22 – SCL**
- I2C clock line; synchronizes with SDA for reliable transmission.
- Used by RTC, BME680, Qwiic.

**IO23 – EPD_RST**
- Resets the EPD circuit before initialization or display updates.
- Used by E-Paper Display.

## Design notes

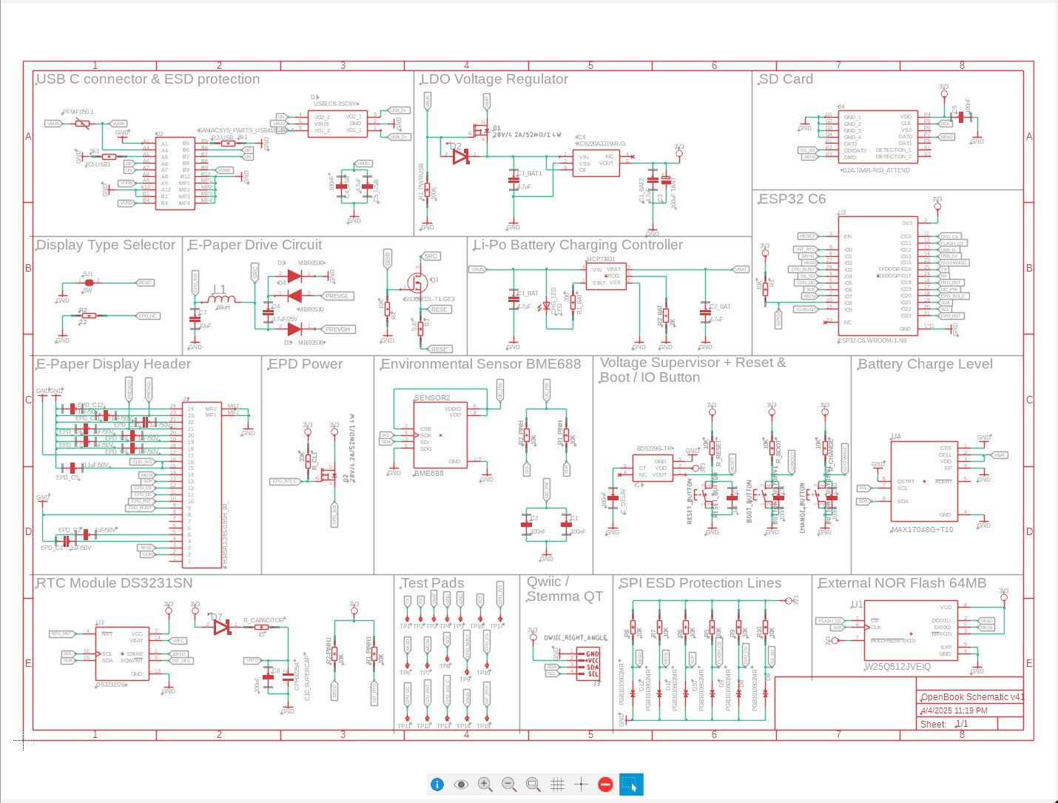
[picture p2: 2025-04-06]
Images/Schematic.JPG

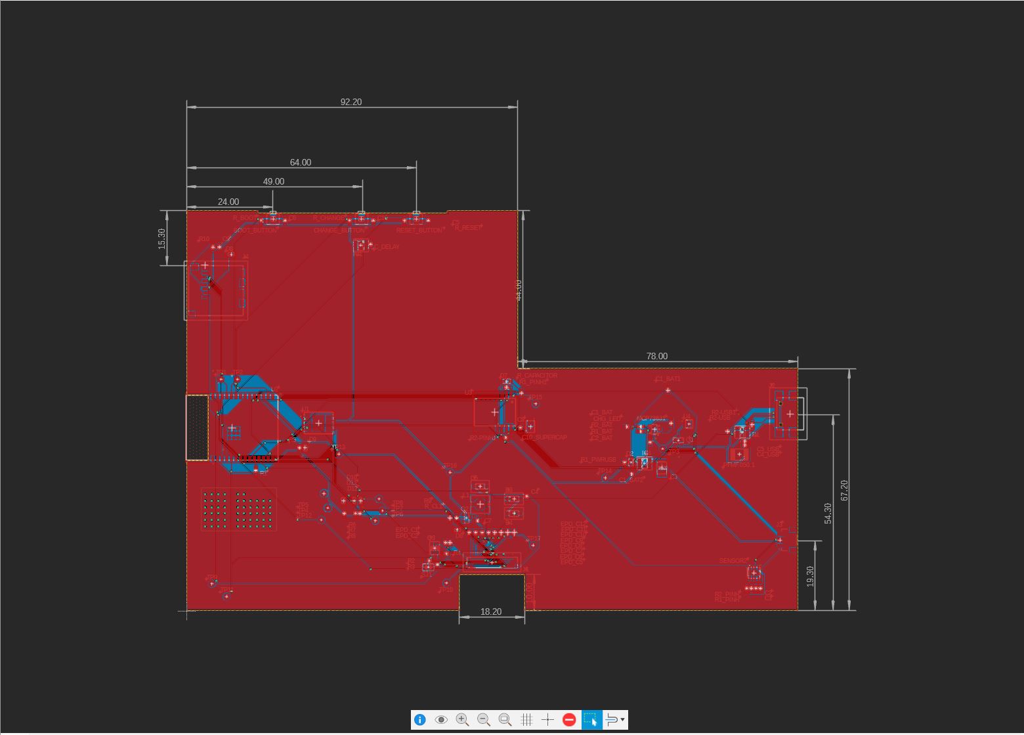
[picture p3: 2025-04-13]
Images/Ground Plan PCB.JPG

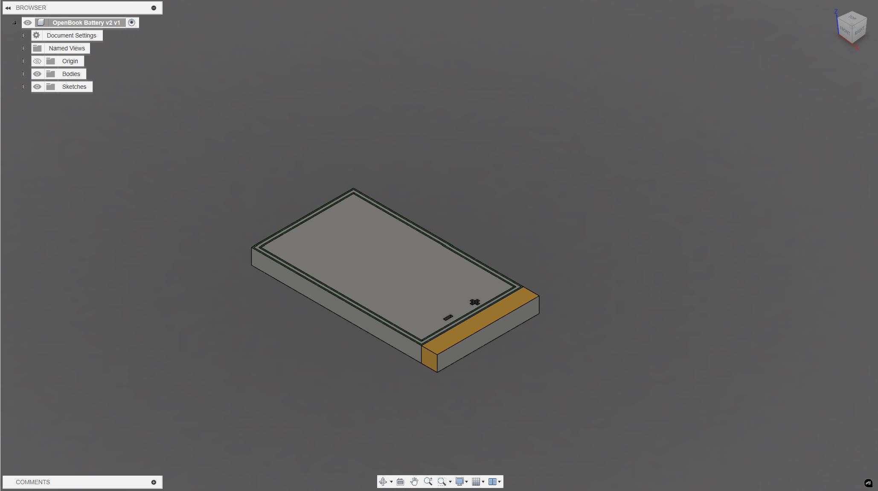
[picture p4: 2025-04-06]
Images/Battery.JPG

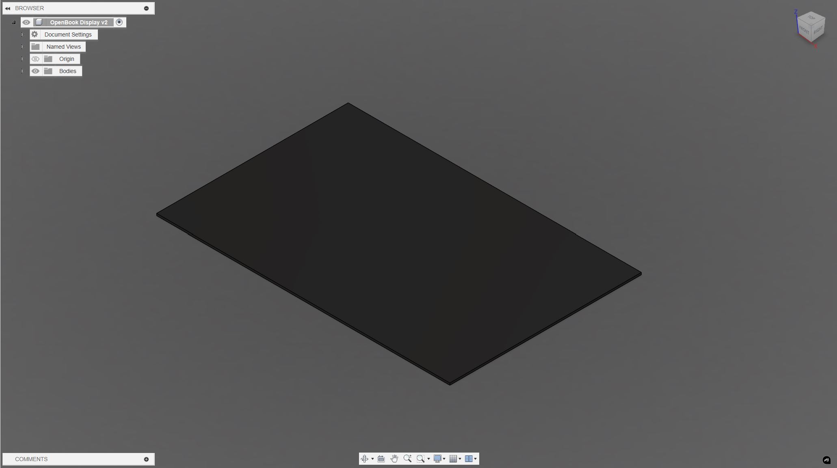
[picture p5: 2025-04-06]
Images/Display.JPG

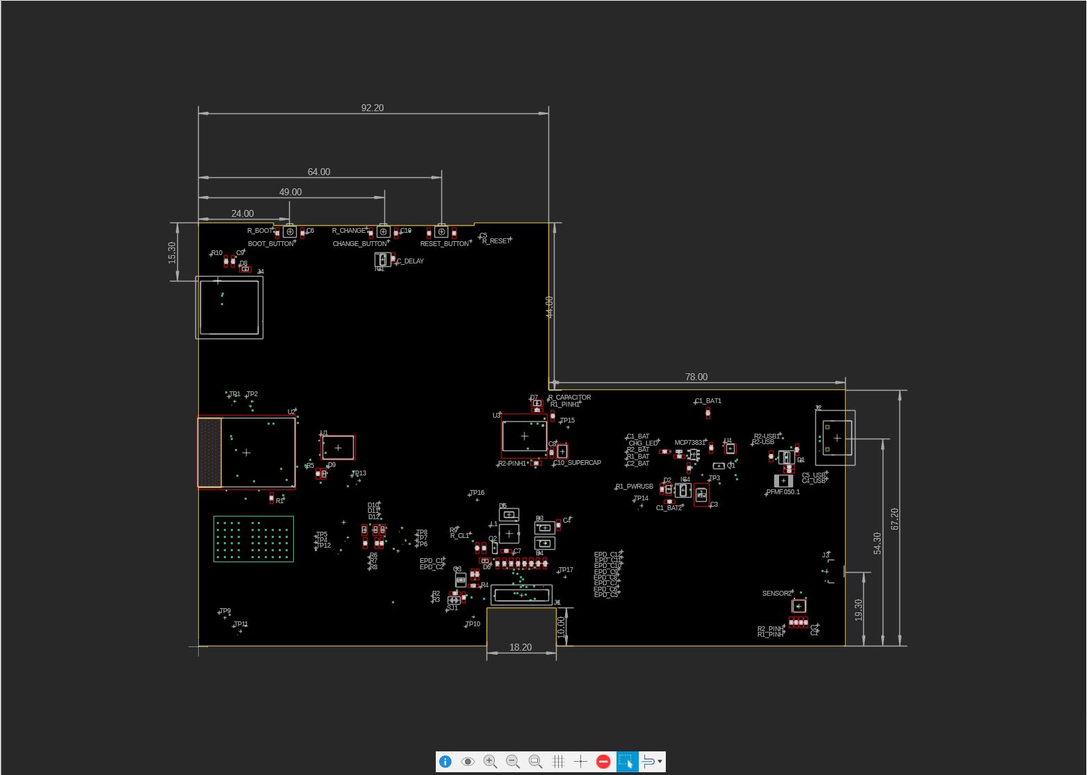
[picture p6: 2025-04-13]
Images/PCB.JPG

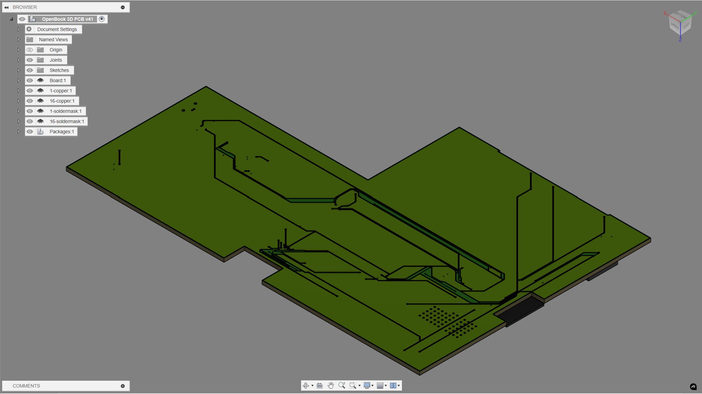
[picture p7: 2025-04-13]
Images/3D PCB BACK.JPG

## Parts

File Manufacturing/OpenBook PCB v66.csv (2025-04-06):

Qty | Value | Device | Package | Parts | Description | ARROW_PART_NUMBER | ARROW_PRICE-STOCK | AVAILABILITY | CENTROID_NOT_SPECIFIED | CHECK_PRICES | COPYRIGHT | DATASHEET | DESCRIPTION | DIGIKEY_DESCRIPTION | DIGIKEY_PART_NUMBER | HEIGHT | LEAD_FREE | MANUFACTURER_NAME | MANUFACTURER_PART_NUMBER | MF | MFR_NAME | MOUSER_PART_NUMBER | MOUSER_PRICE-STOCK | MOUSER_TESTING_PART_NUMBER | MOUSER_TESTING_PRICE-STOCK | MP | MPN | PACKAGE | POPULARITY | PREFIX | PRICE | PROD_ID | PURCHASE-URL | ROHS | SNAPEDA_LINK | SPICEMODEL | SPICEPREFIX | TEMPERATURE_RANGE_HIGH | TEMPERATURE_RANGE_LOW | TP_SIGNAL_NAME | VALUE
1 | 0.1uF/50V | EAGLE-LTSPICE_CC0402 | EAGLE-LTSPICE_C0402 | EPD_C5 | CAPACITOR, European symbol |  |  |  |  |  |  |  |  |  |  |  |  |  |  |  |  |  |  |  |  |  |  |  |  |  |  |  |  |  |  | NONE | C
1 | 0.47 | ESP32_WROVER_EAGLE-LTSPICE_RR0402 | ESP32_WROVER_EAGLE-LTSPICE_R0402 | R3 | RESISTOR, European symbol |  |  |  |  |  |  |  |  |  |  |  |  |  |  |  |  |  |  |  |  |  |  |  |  |  |  |  |  |  |  | NONE | R
1 | 100K | ESP32_WROVER_EAGLE-LTSPICE_RR0402 | ESP32_WROVER_EAGLE-LTSPICE_R0402 | R1_PWRUSB | RESISTOR, European symbol |  |  |  |  |  |  |  |  |  |  |  |  |  |  |  |  |  |  |  |  |  |  |  |  |  |  |  |  |  |  | NONE | R
8 | 100nF | EAGLE-LTSPICE_CC0402 | EAGLE-LTSPICE_C0402 | C1, C2, C4_USB, C6, C8, C9, C10, C_DELAY | CAPACITOR, European symbol |  |  |  |  |  |  |  |  |  |  |  |  |  |  |  |  |  |  |  |  |  |  |  |  |  |  |  |  |  |  | NONE | C
1 | 100uF TANT | RCL_CPOL-EUCT3528 | RCL_CT3528 | C3 | POLARIZED CAPACITOR, European symbol |  |  |  |  |  |  |  |  |  |  |  |  |  |  |  |  |  |  |  |  |  |  |  | 0 |  |  |  |  |  |  |  | C
16 | 10K | ESP32_WROVER_EAGLE-LTSPICE_RR0402 | ESP32_WROVER_EAGLE-LTSPICE_R0402 | R1, R1_PINH, R1_PINH1, R2-PINH1, R2_PINH, R4, R5, R6, R7, R8, R9, R10, R_BOOT, R_CHANGE, R_CL1, R_RESET | RESISTOR, European symbol |  |  |  |  |  |  |  |  |  |  |  |  |  |  |  |  |  |  |  |  |  |  |  |  |  |  |  |  |  |  | NONE | R
1 | 10uF | EAGLE-LTSPICE_CC0402 | EAGLE-LTSPICE_C0402 | C7 | CAPACITOR, European symbol |  |  |  |  |  |  |  |  |  |  |  |  |  |  |  |  |  |  |  |  |  |  |  |  |  |  |  |  |  |  | NONE | C
1 | 112A-TAAR-R03_ATTEND | 112A-TAAR-R03_ATTEND | 112ATAARR03ATTEND | J4 | Micro SD Card Socket, Push-Push Type, Top Mount, SMT, H=1.83mm, 10u |  |  |  |  |  |  |  | Micro SD Card Socket | Push-Push Type | Top Mount | SMT | H=1.83mm | 10u |  |  | 1.9mm |  | ATTEND | 112A-TAAR-R03 ATTEND
1 | 15 | ESP32_WROVER_EAGLE-LTSPICE_RR0402 | ESP32_WROVER_EAGLE-LTSPICE_R0402 | R_CAPACITOR | RESISTOR, European symbol |  |  |  |  |  |  |  |  |  |  |  |  |  |  |  |  |  |  |  |  |  |  |  |  |  |  |  |  |  |  | NONE | R
1 | 1uF | EAGLE-LTSPICE_CC0402 | EAGLE-LTSPICE_C0402 | C5 | CAPACITOR, European symbol |  |  |  |  |  |  |  |  |  |  |  |  |  |  |  |  |  |  |  |  |  |  |  |  |  |  |  |  |  |  | NONE | C
9 | 1uF/50V | EAGLE-LTSPICE_CC0402 | EAGLE-LTSPICE_C0402 | EPD_C1, EPD_C2, EPD_C6, EPD_C7, EPD_C8, EPD_C9, EPD_C10, EPD_C11, EPD_C12 | CAPACITOR, European symbol |  |  |  |  |  |  |  |  |  |  |  |  |  |  |  |  |  |  |  |  |  |  |  |  |  |  |  |  |  |  | NONE | C
1 | 2.2 | ESP32_WROVER_EAGLE-LTSPICE_RR0402 | ESP32_WROVER_EAGLE-LTSPICE_R0402 | R2 | RESISTOR, European symbol |  |  |  |  |  |  |  |  |  |  |  |  |  |  |  |  |  |  |  |  |  |  |  |  |  |  |  |  |  |  | NONE | R
1 | 200 | ESP32_WROVER_EAGLE-LTSPICE_RR0402 | ESP32_WROVER_EAGLE-LTSPICE_R0402 | R1_BAT | RESISTOR, European symbol |  |  |  |  |  |  |  |  |  |  |  |  |  |  |  |  |  |  |  |  |  |  |  |  |  |  |  |  |  |  | NONE | R
2 | 20V/4.2A/52mO/1.4W | ESP32_WROVER_SPARKFUN-DISCRETESEMI_MOSFET_PCH-DMG2305UX-7 | ESP32_WROVER_SPARKFUN-DISCRETESEMI_SOT23-3 | Q1, Q2 | P-channel MOSFETs |  |  |  |  |  |  |  |  |  |  |  |  |  |  |  |  |  |  |  |  |  |  |  |  |  |  | TRAN-14388 |  |  |  |  |  |  |  |  | 20V/4.2A/52mO/1.4W
1 | 2K | ESP32_WROVER_EAGLE-LTSPICE_RR0402 | ESP32_WROVER_EAGLE-LTSPICE_R0402 | R2_BAT | RESISTOR, European symbol |  |  |  |  |  |  |  |  |  |  |  |  |  |  |  |  |  |  |  |  |  |  |  |  |  |  |  |  |  |  | NONE | R
5 | 4.7uF | EAGLE-LTSPICE_CC0402 | EAGLE-LTSPICE_C0402 | C1_BAT, C1_BAT1, C1_BAT2, C2_BAT, C5_USB | CAPACITOR, European symbol |  |  |  |  |  |  |  |  |  |  |  |  |  |  |  |  |  |  |  |  |  |  |  |  |  |  |  |  |  |  | NONE | C
1 | 4.7uF/25V | EAGLE-LTSPICE_CC0402 | EAGLE-LTSPICE_C0402 | C4 | CAPACITOR, European symbol |  |  |  |  |  |  |  |  |  |  |  |  |  |  |  |  |  |  |  |  |  |  |  |  |  |  |  |  |  |  | NONE | C
2 | 5k1 | ESP32_WROVER_EAGLE-LTSPICE_RR0402 | ESP32_WROVER_EAGLE-LTSPICE_R0402 | R2-USB, R2-USB1 | RESISTOR, European symbol |  |  |  |  |  |  |  |  |  |  |  |  |  |  |  |  |  |  |  |  |  |  |  |  |  |  |  |  |  |  | NONE | R
1 | 68uH | 744043680IND_4828-WE-TPC_WRE | IND_4828-WE-TPC_WRE | L1 |  |  |  |  |  |  | Copyright (C) 2024 Ultra Librarian. All rights reserved. |  |  |  |  |  |  |  | 744043680 |  | Wurth Electronics
1 | BD5229G-TR | BD5229G-TR | SOT95P280X125-5N | IC1 | Voltage Detector with Adjustable Delay Time: CMOS processes are utilized to develop high precision, low current consumption CMOS reset ICs that allow arbitrary setting of the delay time. The extensive lineup includes both Nch Open Drain and CMOS output types in a wide range of detection voltages (from 2.3V to 6.0V, in 0.1V steps), enabling selection of the ideal solution based on customer requirements. In addition, the entire series is of course both lead-free and RoHS-compliant. |  |  |  |  |  |  |  | Voltage Detector with Adjustable Delay Time: CMOS processes are utilized to develop high precision | low current consumption CMOS reset ICs that allow arbitrary setting of the delay time. The extensive lineup includes both Nch Open Drain and CMOS output types in a wide range of detection voltages (from 2.3V to 6.0V | in 0.1V steps) | enabling selection of the ideal solution based on customer requirements. In addition | the entire series is of course both lead-free and RoHS-compliant. |  |  | 1.25mm |  | ROHM Semiconductor | BD5229G-TR |  |  | 755-BD5229G-TR | https://www.mouser.co.uk/ProductDetail/ROHM-Semiconductor/BD5229G-TR?qs=4kLU8WoGk0vvnhrrYwdszw%3D%3D
1 | BME688 | ESP32_WROVER_BME680_BME680 | ESP32_WROVER_BME680_PSON80P300X300X100-8N | SENSOR2 | Integrated Environmental Unit |  |  | Unavailable |  |  |  |  | Integrated Environmental Unit |  |  |  |  |  |  | Bosch Sensortec |  |  |  |  |  | BME680 |  | LGA-8 Bosch Tools |  |  | None
2 | BUTTON_CUSYOMV1 | BUTTON_CUSYOMV1 | MYBUTTON | BOOT_BUTTON, CHANGE_BUTTON
1 | CPH3225A | CPH3225A | CAPCP3225X100N | C10_SUPERCAP | Cap 0.011F 3.3V 1210 Flat Check availability |  |  | Not in stock |  | https://www.snapeda.com/parts/CPH3225A/Seiko+Instruments/view-part/?ref=eda |  |  | 11 mF (EDLC) Supercapacitor 3.3 V 1210 (3225 Metric) - - |  |  |  |  |  |  | Seiko Instruments |  |  |  |  |  | CPH3225A |  | 1210 Seiko |  |  | None |  | https://www.snapeda.com/api/url_track_click_mouser/?unipart_id=562593&manufacturer=Seiko Instruments&part_name=CPH3225A&search_term=None |  | https://www.snapeda.com/parts/CPH3225A/Seiko+Instruments/view-part/?ref=snap
1 | DS3231SN# | DS3231SN# | SOIC127P1032X265-16N | U3 | Real Time Clock Serial 16-Pin SOIC W T/R Check availability |  |  | In Stock |  | https://www.snapeda.com/parts/DS3231SN%23/Analog+Devices/view-part/?ref=eda |  |  | Extremely Accurate I²C-Integrated RTC/TCXO/Crystal |  |  |  |  |  |  | Analog Devices |  |  |  |  |  | DS3231SN# |  | SOIC-16 Maxim |  |  | None |  | https://www.snapeda.com/api/url_track_click_mouser/?unipart_id=99048&manufacturer=Analog Devices&part_name=DS3231SN#&search_term=None |  | https://www.snapeda.com/parts/DS3231SN%23/Analog+Devices/view-part/?ref=snap
1 | ESP32-C6-WROOM-1-N8 | ESP32-C6-WROOM-1-N8 | XCVR_ESP32-C6-WROOM-1-N8 | U2 | Check availability |  |  | In Stock |  | https://www.snapeda.com/parts/ESP32-C6-WROOM-1-N8/Espressif+Systems/view-part/?ref=eda |  |  | Multiprotocol Modules ESP32-C6 module | Wi-Fi 6 in 2.4 GHz band | Bluetooth 5 | Zigbee 3.0 and Thread. ESP34-WROOM Compatible - ENGINEERING SAMPLE |  |  |  |  |  |  | Espressif Systems |  |  |  |  |  | ESP32-C6-WROOM-1-N8 |  | None |  |  | None |  |  |  | https://www.snapeda.com/parts/ESP32-C6-WROOM-1-N8/Espressif+Systems/view-part/?ref=snap
1 | ESP32C6_VARISTORCN1812 | ESP32C6_VARISTORCN1812 | ESP32C6_VARISTOR_CT/CN1812 | PFMF.050.1 | VARISTOR |  |  |  |  |  |  |  |  |  |  |  |  |  |  |  |  |  |  |  |  |  |  |  | 0
2 | ESP32_WROVER_AVX---SD0805S020S1R0_AVX_SD0805S020S1R0_0_0AVX_SD0805S020S1R0_0_0 | ESP32_WROVER_AVX---SD0805S020S1R0_AVX_SD0805S020S1R0_0_0AVX_SD0805S020S1R0_0_0 | ESP32_WROVER_AVX---SD0805S020S1R0_AVX_SD0805S020S1R0_0 | D2, D7 | Schottky Barrier Rectifier Diode |  |  |  | No |  |  | http://datasheets.avx.com/schottky.pdf |  | DIODE SCHOTTKY 20V 1A 0805 | 478-7800-1-ND |  | yes |  |  | AVX |  | 581-SD0805S020S1R0 |  |  |  |  |  | 0805 (2012 metric) |  | D |  |  |  | yes |  |  |  | +125°C | -55°C
1 | ESP32_WROVER_SPARKFUN-IC-POWER_MCP73831 | ESP32_WROVER_SPARKFUN-IC-POWER_MCP73831 | ESP32_WROVER_SPARKFUN-IC-POWER_SOT23-5 | MCP73831 | MCP73831T Li-Ion, Li-Pol Controller |  |  |  |  |  |  |  |  |  |  |  |  |  |  |  |  |  |  |  |  |  |  |  |  |  |  | IC-09995
1 | FH34SRJ-24S-0.5SH_99_ | FH34SRJ-24S-0.5SH_99_ | FH34SRJ24S05SH99 | J1 | (0.50mm) Surface Mount, Right Angle |  |  |  |  |  |  |  | 24 Position FFC | FPC Connector Contacts | (0.50mm) Surface Mount | Right Angle |  |  | 1.1mm |  | Hirose | FH34SRJ-24S-0.5SH(99) |  |  | 798-FH34SRJ24S05SH99 | https://www.mouser.co.uk/ProductDetail/Hirose-Connector/FH34SRJ-24S-0.5SH99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
1 | LED | ADAFRUIT_LEDCHIP-LED0603 | ADAFRUIT_CHIP-LED0603 | CHG_LED | LED
1 | MAX17048G+T10 | MAX17048G+T10 | SON50P200X200X80-9N | U4 | Check availability |  |  | In Stock |  | https://www.snapeda.com/parts/MAX17048G+T10/Analog+Devices/view-part/?ref=eda |  |  | 3µA 1-Cell/2-Cell Fuel Gauge with ModelGauge |  |  |  |  |  |  | Analog Devices |  |  |  |  |  | MAX17048G+T10 |  | TDFN-8 Maxim |  |  | None |  | https://www.snapeda.com/api/url_track_click_mouser/?unipart_id=329239&manufacturer=Analog Devices&part_name=MAX17048G+T10&search_term=None |  | https://www.snapeda.com/parts/MAX17048G+T10/Analog+Devices/view-part/?ref=snap
3 | MBR0530 | MBR0530 | SOD3716X135N | D3, D4, D5 | ON SEMICONDUCTOR - MBR0530 - DIODE, SCHOTTKY, 0.5A, 30V, SOD-123 |  |  | In Stock |  | https://www.snapeda.com/parts/MBR0530/Onsemi/view-part/?ref=eda |  |  | Diode Schottky 30 V 500mA Surface Mount SOD-123 |  |  |  |  |  |  | ON Semiconductor |  |  |  |  |  | MBR0530 |  | SOD-123-2 ON Semiconductor |  |  | None |  | https://www.snapeda.com/api/url_track_click_mouser/?unipart_id=179458&manufacturer=ON Semiconductor&part_name=MBR0530&search_term=None |  | https://www.snapeda.com/parts/MBR0530/Onsemi/view-part/?ref=snap
6 | PGB1010603MR | PGB1010603MR | DIOC1608X36N | D6, D8, D9, D10, D11, D12 | Check availability |  |  | In Stock |  | https://www.snapeda.com/parts/PGB1010603MR/Littelfuse/view-part/?ref=eda |  |  | 150V (Typ) Clamp - Ipp Tvs Diode Surface Mount 0603 (1608 Metric) |  |  |  |  |  |  | Littelfuse Inc. |  |  |  |  |  | PGB1010603MR |  | 0603 Littelfuse Inc. |  |  | None |  | https://www.snapeda.com/api/url_track_click_mouser/?unipart_id=5659453&manufacturer=Littelfuse Inc.&part_name=PGB1010603MR&search_term=None |  | https://www.snapeda.com/parts/PGB1010603MR/Littelfuse/view-part/?ref=snap
1 | QWIIC_RIGHT_ANGLE | QWIIC_CONNECTORJS-1MM | JST04_1MM_RA | J3 | SparkFun I2C Standard Qwiic Connector |  |  |  |  |  |  |  |  |  |  |  |  |  |  |  |  |  |  |  |  |  |  |  |  |  |  | CONN-13694 |  |  |  |  |  |  |  |  | QWIIC_RIGHT_ANGLE
1 | RESET_BUTTON | BUTTON_CUSYOMV1 | MYBUTTON | RESET_BUTTON
1 | SAMACSYS_PARTS_USB4110-GF-A | SAMACSYS_PARTS_USB4110-GF-A | SAMACSYS_PARTS_USB4110GFA | J2 | CONN USB 2.0 TYPE-C R/A SMT |  |  |  |  |  |  |  | CONN USB 2.0 TYPE-C R/A SMT |  |  | 3.26mm |  | GCT (GLOBAL CONNECTOR TECHNOLOGY) | USB4110-GF-A |  |  | 640-USB4110-GF-A | https://www.mouser.co.uk/ProductDetail/GCT/USB4110-GF-A?qs=KUoIvG%2F9IlYiZvIXQjyJeA%3D%3D
1 | SI1308EDL-T1-GE3 | SI1308EDL-T1-GE3 | SOT65P210X110-3N | Q3 | MOSFET N-Ch 30V 1.5A TrenchFET SC70 Vishay Si1308EDL-T1-GE3 N-channel MOSFET Transistor, 1.5 A, 30 V, 3-Pin SC-70 |  |  | In Stock |  | https://www.snapeda.com/parts/SI1308EDL-T1-GE3/Vishay+Siliconix/view-part/?ref=eda |  |  | Si1308EDL-T1-GE3 N-channel MOSFET Transistor | 1.5 A | 30 V | 3-Pin SC-70 | Siliconix / Vishay SI1308EDL-T1-GE3 |  |  |  |  |  |  | Vishay Siliconix |  |  |  |  |  | SI1308EDL-T1-GE3 |  | SOT-323 Vishay Semiconductor |  |  | None |  | https://www.snapeda.com/api/url_track_click_mouser/?unipart_id=274603&manufacturer=Vishay Siliconix&part_name=SI1308EDL-T1-GE3&search_term=None |  | https://www.snapeda.com/parts/SI1308EDL-T1-GE3/Vishay+Siliconix/view-part/?ref=snap
1 | SW | SJ | SJ | SJ1 | SMD solder JUMPER |  |  |  |  |  |  |  |  |  |  |  |  |  |  |  |  |  |  |  |  |  |  |  | 3
17 | TPTP20R | TPTP20R | TP20R | TP1, TP2, TP3, TP4, TP5, TP6, TP7, TP8, TP9, TP10, TP11, TP12, TP13, TP14, TP15, TP16, TP17 | Test pad |  |  |  |  |  |  |  |  |  |  |  |  |  |  |  |  |  |  |  |  |  |  |  | 2
1 | USBLC6-2SC6Y | USBLC6-2SC6Y | SOT95P280X145-6N | D1 | Low Cap. ESD Protection Auto SOT-23-6 STMicroelectronics USBLC6-2SC6Y, Dual Uni-Directional TVS Diode Array, 6-Pin SOT-23 |  |  | In Stock |  | https://www.snapeda.com/parts/USBLC6-2SC6Y/STMicroelectronics/view-part/?ref=eda |  |  | 17V Clamp 5A (8/20µs) Ipp Tvs Diode Surface Mount SOT-23-6 |  |  |  |  |  |  | STMicroelectronics |  |  |  |  |  | USBLC6-2SC6Y |  | SOT-23-6 STMicroelectronics |  |  | None |  |  |  | https://www.snapeda.com/parts/USBLC6-2SC6Y/STMicroelectronics/view-part/?ref=snap
1 | W25Q512JVEIQ | W25Q512JVEIQ | SON127P600X800X80-9N | U1 | Check availability |  |  | In Stock |  | https://www.snapeda.com/parts/W25Q512JVEIQ/Winbond+Electronics/view-part/?ref=eda |  |  | FLASH - NOR Memory IC 512Mb (64M x 8) SPI - Quad I/O 133 MHz 8-WSON (8x6) |  |  |  |  |  |  | Winbond Electronics |  |  |  |  |  | W25Q512JVEIQ |  | Package |  |  | None |  |  |  | https://www.snapeda.com/parts/W25Q512JVEIQ/Winbond+Electronics/view-part/?ref=snap
1 | XC6220A331MR-G | XC6220A331MR-G | SOT95P280X120-5N | IC4 | LDO Voltage Regulators |  |  |  |  |  |  |  | LDO Voltage Regulators |  |  | 1.2mm |  | Torex | XC6220A331MR-G |  |  | 865-XC6220A331MR-G | https://www.mouser.co.uk/ProductDetail/Torex-Semiconductor/XC6220A331MR-G?qs=AsjdqWjXhJ8ZSWznL1J0gg%3D%3D

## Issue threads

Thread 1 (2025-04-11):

PCB

tanase-ramona, 2025-04-11:
- [ ] Gauri in GND pour (lipsa via stitching)

- [ ]  Numele componentelor nu se afla pe silkscreen top, ci pe names top

Closed 2025-04-13.

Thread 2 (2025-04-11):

Model 3D

tanase-ramona, 2025-04-11:
- [ ] Grosime eronata PCB (1.6mm in loc de 1mm)

- [ ] Model 3D nesugestiv pt Display

- [ ] Inconsistenta dimensiune text in denumirile componentelor

- [ ] Nume componente suprapus cu componentele efective

Closed 2025-04-13.

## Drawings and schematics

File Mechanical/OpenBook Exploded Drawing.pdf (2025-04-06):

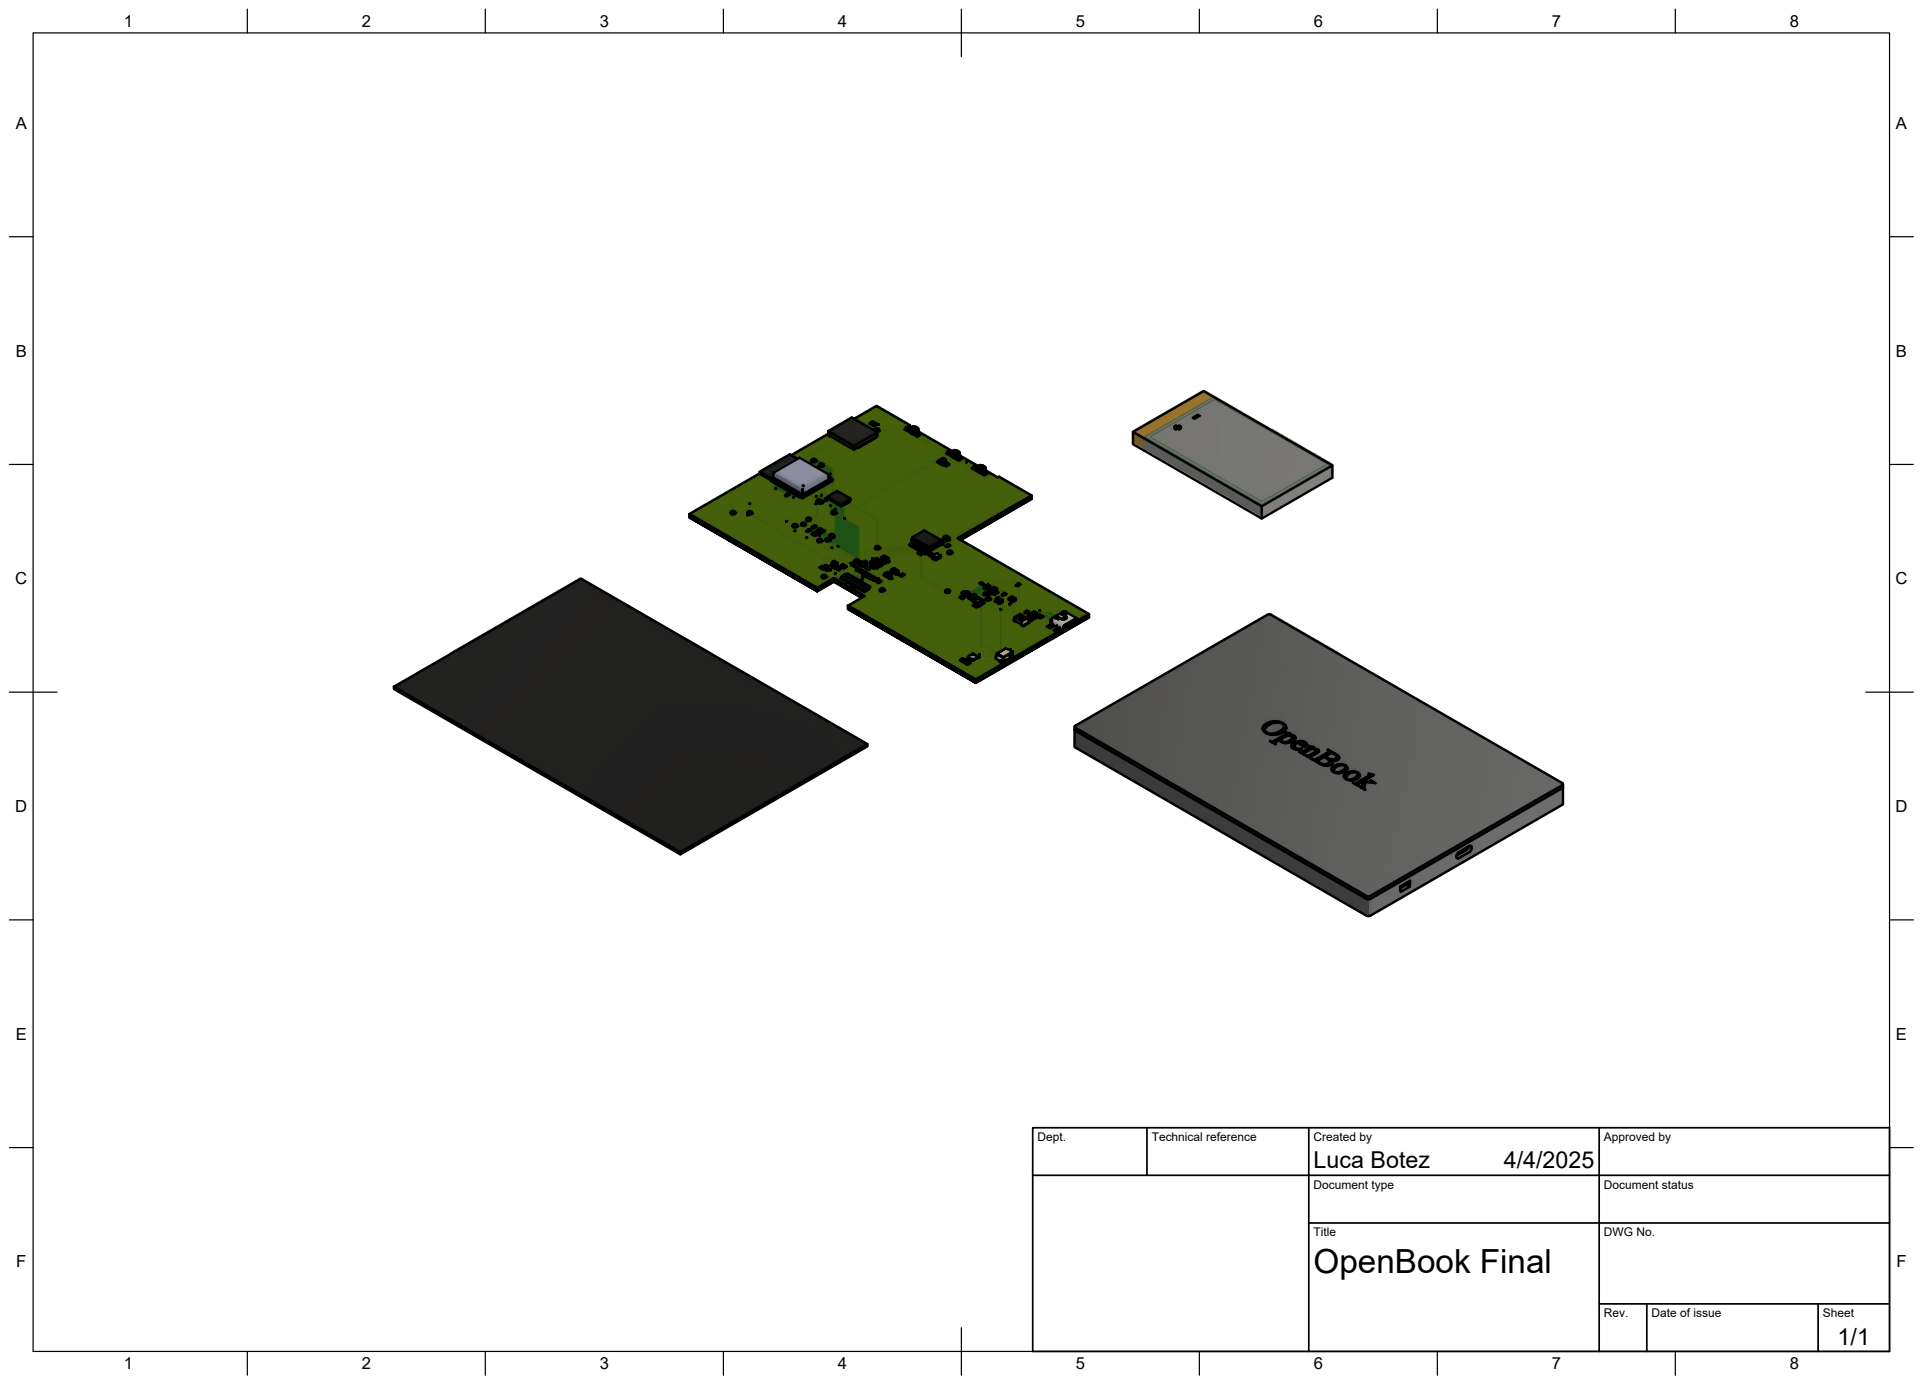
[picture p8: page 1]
Title; DWG No.; Rev.; Date of issue; Sheet; OpenBook Final

Dept. | Technical reference | Created by Luca Botez 4/4/2025 | Approved by

Document type | Document status

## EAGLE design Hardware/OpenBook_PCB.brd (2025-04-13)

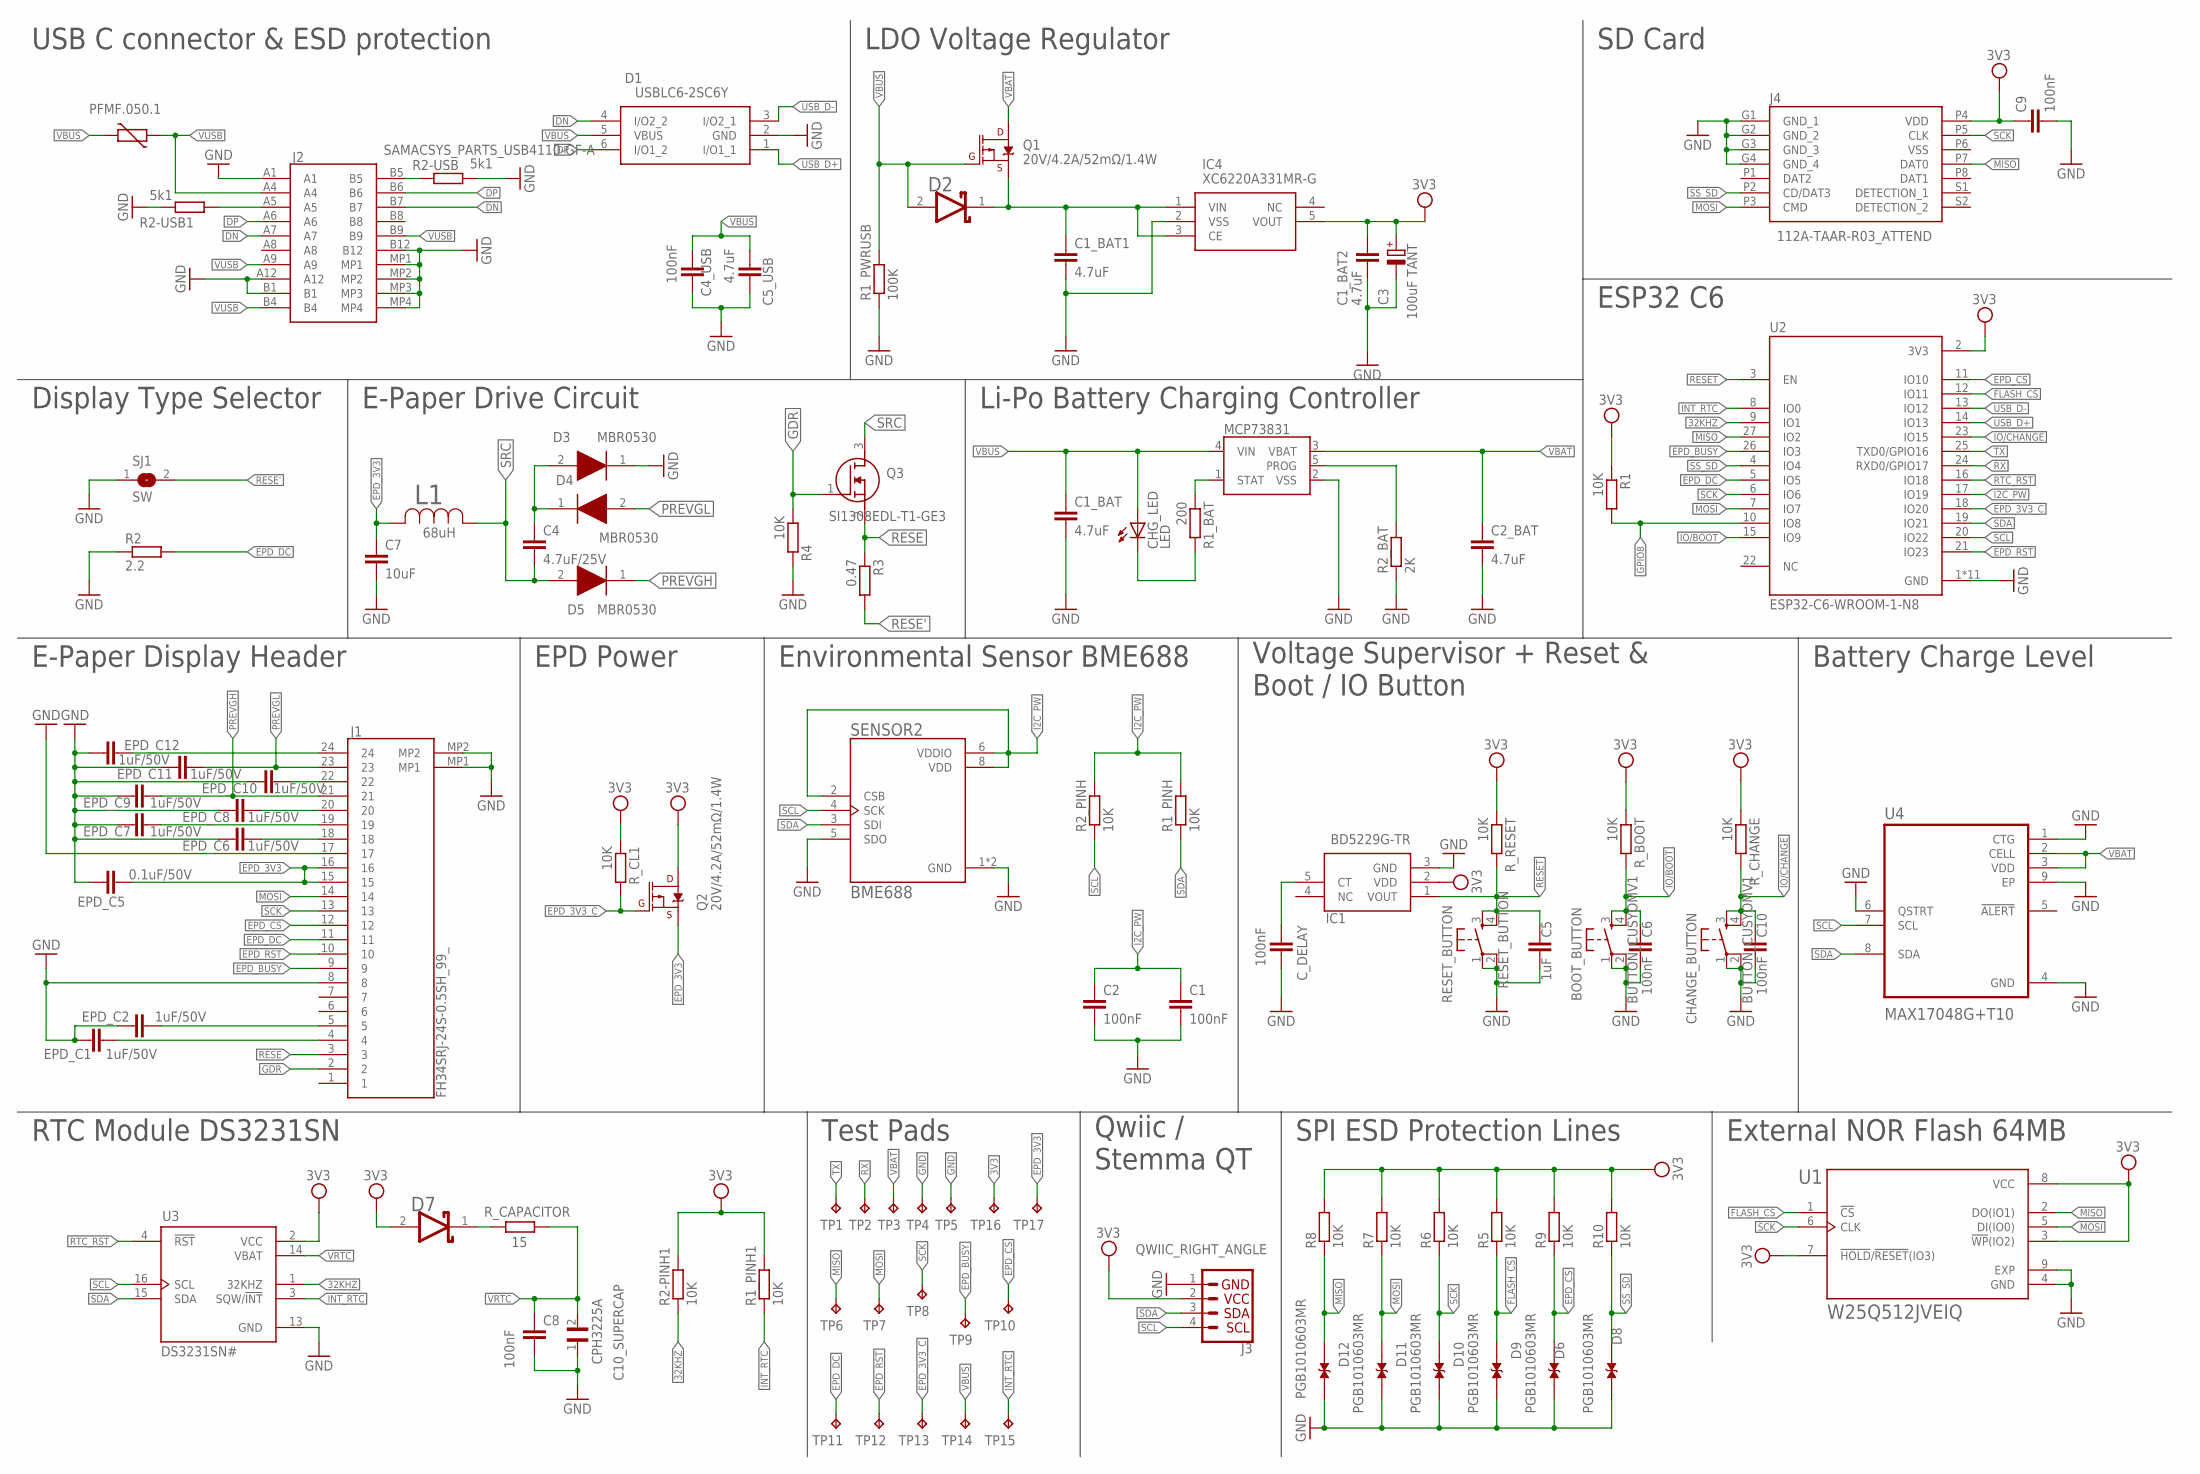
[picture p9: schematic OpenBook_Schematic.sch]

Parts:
BOOT_BUTTON: BUTTON_CUSYOMV1; MYBUTTON
C1, C2, C4_USB, C6, C8, C9, C10: 100nF; EAGLE-LTSPICE_C0402
C1_BAT, C1_BAT1, C1_BAT2, C2_BAT, C5_USB: 4.7uF; EAGLE-LTSPICE_C0402
C3: 100uF TANT; RCL_CT3528
C4: 4.7uF/25V; EAGLE-LTSPICE_C0402
C5: 1uF; EAGLE-LTSPICE_C0402
C7: 10uF; EAGLE-LTSPICE_C0402
C10_SUPERCAP: CPH3225A; CAPCP3225X100N
CHANGE_BUTTON: BUTTON_CUSYOMV1; MYBUTTON
CHG_LED: LED; ADAFRUIT_CHIP-LED0603
C_DELAY: 100nF; EAGLE-LTSPICE_C0402
D1: USBLC6-2SC6Y; SOT95P280X145-6N
D2, D7: ESP32_WROVER_AVX---SD0805S020S1R0_AVX_SD0805S020S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; ESP32_WROVER_AVX---SD0805S020S1R0_AVX_SD0805S020S1R0_0
D3, D4, D5: MBR0530; SOD3716X135N
D6, D8, D9, D10, D11, D12: PGB1010603MR; DIOC1608X36N
EPD_C1, EPD_C2, EPD_C6, EPD_C7, EPD_C8, EPD_C9, EPD_C10, EPD_C11, EPD_C12: 1uF/50V; EAGLE-LTSPICE_C0402
EPD_C5: 0.1uF/50V; EAGLE-LTSPICE_C0402
IC1: BD5229G-TR; SOT95P280X125-5N
IC4: XC6220A331MR-G; SOT95P280X120-5N
J1: FH34SRJ-24S-0.5SH_99_; FH34SRJ24S05SH99
J2: SAMACSYS_PARTS_USB4110-GF-A; SAMACSYS_PARTS_USB4110GFA
J3: QWIIC_RIGHT_ANGLE; JST04_1MM_RA
J4: 112A-TAAR-R03_ATTEND; 112ATAARR03ATTEND
L1: 68uH; IND_4828-WE-TPC_WRE
MCP73831: ESP32_WROVER_SPARKFUN-IC-POWER_MCP73831; ESP32_WROVER_SPARKFUN-IC-POWER_SOT23-5
PFMF.050.1: ESP32C6_VARISTORCN1812; ESP32C6_VARISTOR_CT/CN1812
Q1, Q2: 20V/4.2A/52mΩ/1.4W; ESP32_WROVER_SPARKFUN-DISCRETESEMI_SOT23-3
Q3: SI1308EDL-T1-GE3; SOT65P210X110-3N
R1, R1_PINH, R1_PINH1, R2-PINH1, R2_PINH, R4, R5, R6, R7, R8, R9, R10: 10K; ESP32_WROVER_EAGLE-LTSPICE_R0402
R1_BAT: 200; ESP32_WROVER_EAGLE-LTSPICE_R0402
R1_PWRUSB: 100K; ESP32_WROVER_EAGLE-LTSPICE_R0402
R2: 2.2; ESP32_WROVER_EAGLE-LTSPICE_R0402
R2-USB, R2-USB1: 5k1; ESP32_WROVER_EAGLE-LTSPICE_R0402
R2_BAT: 2K; ESP32_WROVER_EAGLE-LTSPICE_R0402
R3: 0.47; ESP32_WROVER_EAGLE-LTSPICE_R0402
RESET_BUTTON: RESET_BUTTON; MYBUTTON
R_BOOT: 10K; ESP32_WROVER_EAGLE-LTSPICE_R0402
R_CAPACITOR: 15; ESP32_WROVER_EAGLE-LTSPICE_R0402
R_CHANGE: 10K; ESP32_WROVER_EAGLE-LTSPICE_R0402
R_CL1: 10K; ESP32_WROVER_EAGLE-LTSPICE_R0402
R_RESET: 10K; ESP32_WROVER_EAGLE-LTSPICE_R0402
SENSOR2: BME688; ESP32_WROVER_BME680_PSON80P300X300X100-8N
SJ1: SW; SJ
TP1, TP2, TP3, TP4, TP5, TP6, TP7, TP8, TP9, TP10, TP11, TP12, TP13, TP14, TP15, TP16, TP17: TPTP20R; TP20R
U1: W25Q512JVEIQ; SON127P600X800X80-9N
U2: ESP32-C6-WROOM-1-N8; XCVR_ESP32-C6-WROOM-1-N8
U3: DS3231SN#; SOIC127P1032X265-16N
U4: MAX17048G+T10; SON50P200X200X80-9N

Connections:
3V3: C1_BAT2.1, C3.+, C9.1, D7.2 (ANODE), IC1.2 (VDD), IC4.5 (VOUT), J3.2, J4.P4 (VDD), Q2.3 (D), R1.1, R1_PINH1.2, R2-PINH1.2, R5.2, R6.2, R7.2, R8.2, R9.2, R10.2, R_BOOT.1, R_CHANGE.1, R_CL1.1, R_RESET.1, TP16.TP, U1.3 (!WP!(IO2)), U1.7 (!HOLD!/!RESET!(IO3)), U1.8 (VCC), U2.2 (3V3), U3.2 (VCC)
32KHZ: R2-PINH1.1, U2.9 (IO1), U3.1 (32KHZ)
DN: D1.4 (I/O2_2), J2.A7, J2.B7
DP: D1.6 (I/O1_2), J2.A6, J2.B6
EPD_3V3: C7.1, EPD_C5.1, J1.15, J1.16, L1.2, Q2.2 (S), TP17.TP
EPD_3V3_C: Q2.1 (G), R_CL1.2, TP13.TP, U2.18 (IO20)
EPD_BUSY: J1.9, TP9.TP, U2.26 (IO3)
EPD_CS: D6.1, J1.12, R9.1, TP10.TP, U2.11 (IO10)
EPD_DC: J1.11, R2.2, TP11.TP, U2.5 (IO5)
EPD_RST: J1.10, TP12.TP, U2.21 (IO23)
FLASH_CS: D9.1, R5.1, U1.1 (!CS), U2.12 (IO11)
GDR: J1.2, Q3.1 (G), R4.1
GND: BOOT_BUTTON.1, BOOT_BUTTON.2, C1.2, C1_BAT.2, C1_BAT1.2, C1_BAT2.2, C2.2, C2_BAT.2, C3.-, C4_USB.2, C5.2, C5_USB.2, C6.2, C7.2, C8.2, C9.2, C10.2, C10_SUPERCAP.1, CHANGE_BUTTON.1, CHANGE_BUTTON.2, C_DELAY.2, D1.2 (GND), D3.1 (K), D6.2, D8.2, D9.2, D10.2, D11.2, D12.1, EPD_C1.2, EPD_C2.2, EPD_C5.2, EPD_C6.2, EPD_C7.2, EPD_C8.2, EPD_C9.2, EPD_C10.2, EPD_C11.2, EPD_C12.2, IC1.3 (GND), IC4.2 (VSS), J1.8, J1.17, J1.MP1, J1.MP2, J2.A1, J2.A12, J2.B1, J2.B12, J2.MP1, J2.MP2, J2.MP3, J2.MP4, J3.1, J4.G1 (GND_1), J4.G2 (GND_2), J4.G3 (GND_3), J4.G4 (GND_4), MCP73831.2 (VSS), R1_PWRUSB.1, R2.1, R2-USB.2, R2-USB1.1, R2_BAT.1, R4.2, RESET_BUTTON.1, RESET_BUTTON.2, SENSOR2.1 (GND), SENSOR2.5 (SDO), SENSOR2.7 (GND), SJ1.1, TP4.TP, TP5.TP, U1.4 (GND), U1.9 (EXP), U2.1 (GND), U2.28 (GND), U2.29_1 (GND), U2.29_2 (GND), U2.29_3 (GND), U2.29_4 (GND), U2.29_5 (GND), U2.29_6 (GND), U2.29_7 (GND), U2.29_8 (GND), U2.29_9 (GND), U3.13 (GND), U4.1 (CTG), U4.4 (GND), U4.6 (QSTRT), U4.9 (EP)
GPIO8: R1.2, U2.10 (IO8)
I2C_PW: C1.1, C2.1, R1_PINH.2, R2_PINH.2, SENSOR2.2 (CSB), SENSOR2.6 (VDDIO), SENSOR2.8 (VDD), U2.17 (IO19)
INT_RTC: R1_PINH1.1, TP15.TP, U2.8 (IO0), U3.3 (SQW/!INT)
IO/BOOT: BOOT_BUTTON.3, BOOT_BUTTON.4, C6.1, R_BOOT.2, U2.15 (IO9)
IO/CHANGE: C10.1, CHANGE_BUTTON.3, CHANGE_BUTTON.4, R_CHANGE.2, U2.23 (IO15)
MISO: D12.2, J4.P7 (DAT0), R8.1, TP6.TP, U1.2 (DO(IO1)), U2.27 (IO2)
MOSI: D11.1, J1.14, J4.P3 (CMD), R7.1, TP7.TP, U1.5 (DI(IO0)), U2.7 (IO7)
unnamed: J2.B5, R2-USB.1
unnamed: J2.A5, R2-USB1.2
unnamed: C1_BAT1.1, D2.1 (CATHODE), IC4.1 (VIN), IC4.3 (CE), Q1.2 (S)
unnamed: C4.1, D3.2 (A), D4.1 (K)
unnamed: MCP73831.1 (STAT), R1_BAT.1
unnamed: CHG_LED.C, R1_BAT.2
unnamed: MCP73831.5 (PROG), R2_BAT.2
unnamed: EPD_C2.1, J1.5
unnamed: EPD_C1.1, J1.4
unnamed: EPD_C6.1, J1.18
unnamed: EPD_C7.1, J1.19
unnamed: EPD_C8.1, J1.20
unnamed: C_DELAY.1, IC1.5 (CT)
unnamed: EPD_C10.1, J1.22
unnamed: EPD_C12.1, J1.24
unnamed: D7.1 (CATHODE), R_CAPACITOR.2
PREVGH: D5.1 (K), EPD_C9.1, J1.21
PREVGL: D4.2 (A), EPD_C11.1, J1.23
RESE: J1.3, Q3.2 (S), R3.1
RESE': R3.2, SJ1.2
RESET: C5.1, IC1.1 (VOUT), RESET_BUTTON.3, RESET_BUTTON.4, R_RESET.2, U2.3 (EN)
RTC_RST: U2.16 (IO18), U3.4 (!RST)
RX: TP2.TP, U2.24 (RXD0/GPIO17)
SCK: D10.1, J1.13, J4.P5 (CLK), R6.1, TP8.TP, U1.6 (CLK), U2.6 (IO6)
SCL: J3.4, R2_PINH.1, SENSOR2.4 (SCK), U2.20 (IO22), U3.16 (SCL), U4.7 (SCL)
SDA: J3.3, R1_PINH.1, SENSOR2.3 (SDI), U2.19 (IO21), U3.15 (SDA), U4.8 (SDA)
SRC: C4.2, D5.2 (A), L1.1, Q3.3 (D)
SS_SD: D8.1, J4.P2 (CD/DAT3), R10.1, U2.4 (IO4)
TX: TP1.TP, U2.25 (TXD0/GPIO16)
USB_D+: D1.1 (I/O1_1), U2.14 (IO13)
USB_D-: D1.3 (I/O2_1), U2.13 (IO12)
VBAT: C2_BAT.1, MCP73831.3 (VBAT), Q1.3 (D), TP3.TP, U4.2 (CELL), U4.3 (VDD)
VBUS: C1_BAT.1, C4_USB.1, C5_USB.1, CHG_LED.A, D1.5 (VBUS), D2.2 (ANODE), MCP73831.4 (VIN), PFMF.050.1.2, Q1.1 (G), R1_PWRUSB.2, TP14.TP
VRTC: C8.1, C10_SUPERCAP.2, R_CAPACITOR.1, U3.14 (VBAT)
VUSB: J2.A4, J2.A9, J2.B4, J2.B9, PFMF.050.1.1

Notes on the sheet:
USB C connector & ESD protection
LDO Voltage Regulator
SD Card
Display Type Selector
E-Paper Drive Circuit
Li-Po Battery Charging Controller
ESP32 C6
E-Paper Display Header
EPD Power
Environmental Sensor BME688
Voltage Supervisor + Reset & Boot / IO Button
Battery Charge Level
RTC Module DS3231SN
Test Pads
Qwiic / Stemma QT
SPI ESD Protection Lines
External NOR Flash 64MB

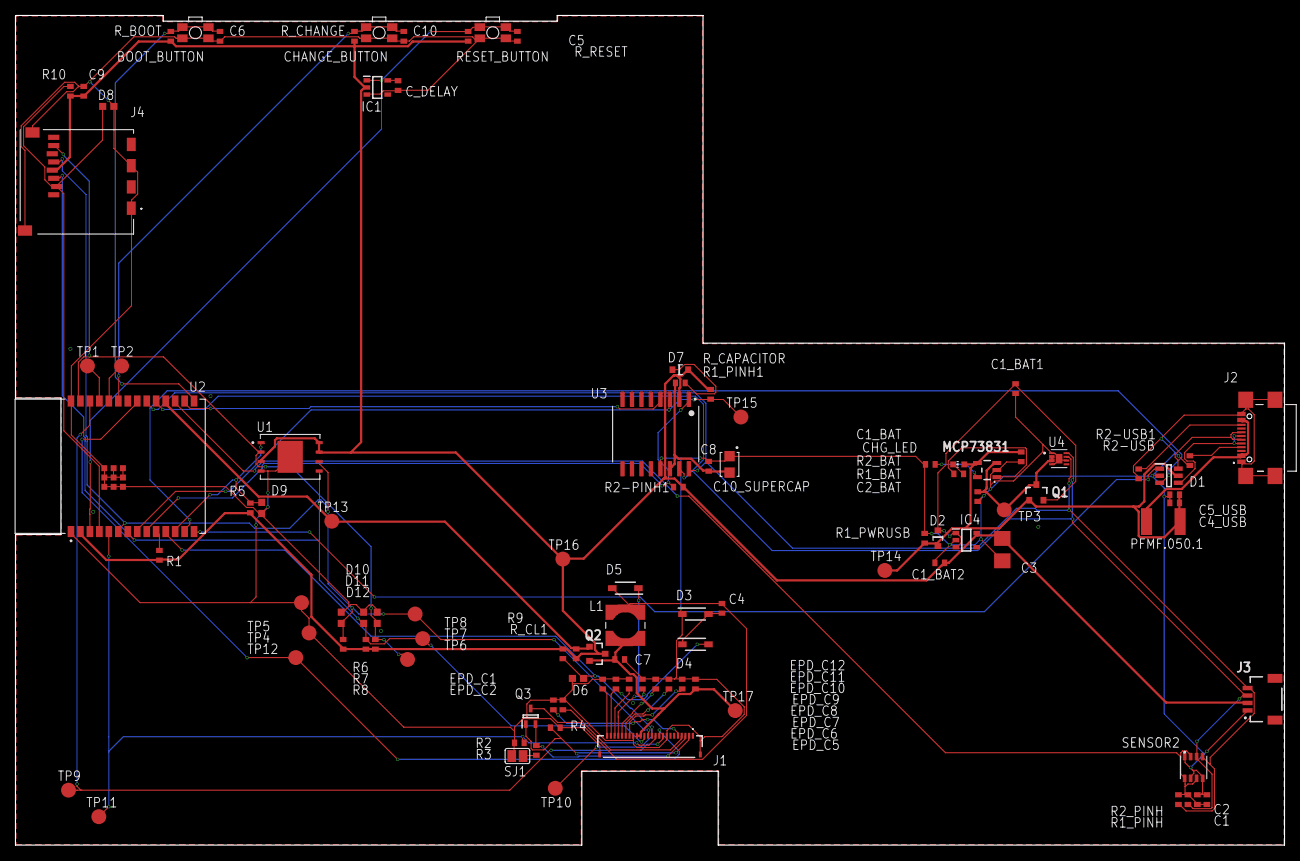
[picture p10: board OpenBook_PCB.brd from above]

Board: 2 copper layers, 170.2 x 111.3 mm, 103 parts (0 on the bottom side), 55 nets.

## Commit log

2025-04-05 Added BOM in README.md
2025-04-06 Added pin information

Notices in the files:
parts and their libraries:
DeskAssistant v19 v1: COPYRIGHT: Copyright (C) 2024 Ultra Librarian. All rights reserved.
